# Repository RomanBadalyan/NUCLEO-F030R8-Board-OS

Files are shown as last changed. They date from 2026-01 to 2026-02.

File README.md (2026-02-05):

 

# Описание

Данный проект представляет собой __полное воссоздание оригинальной отладочной платы STM32 Nucleo-F030R8__ на базе микроконтроллера __STM32F030R8T6.__ Плата разработана с соблюдением всех габаритных размеров и расположения разъемов оригинального устройства, обеспечивая полную совместимость с экосистемой Arduino и ST Morpho.
Если хотите посмотреть всю докуметацию к проекту или самостоятельно воссоздать плату, переходите сразу в раздел ["Для разработчкиов"](https://github.com/RomanBadalyan/NUCLEO-F030R8-Board-OS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)

рисунок самой платы

## :dart: Ключевые особенности

* **100% совместимость** с оригинальной Nucleo-F030R8 по габаритам (70x82.5 мм) и распиновке
* **Двойная функциональность:** работает как отладочная плата и как программатор для других STM32
* **Полный набор интерфейсов:** Arduino Uno R3, ST Morpho, SWD, USB Virtual COM Port
* **Профессиональная 4-слойная структура** РСВ (улучшенная версия оригинальной 2-слойной)
* **Готовность к производству:** все файлы для заказа РСВ и компонентов включены

## :hammer_and_wrench: Технические характеристики

### Микроконтроллеры

* **Основной MCU:** STM32F030R8T6 (Cortex-M0, 64 КБ Flash, 8 КБ RAM, 48 МГц)
* **Программатор/отладчик:** STM32F103CBT6 (Cortex-M3, встроенный ST-LINK/V2-1)

### Питание

* **Вход USB:** 5V (500 мА максимум)
* **Вход VIN**: 7-12V (до 800 мА)
* **Выходы: 3.3V** (500 мА), 5V (до 800 мА)
* **Управление питанием:** Интеллектуальное включение MCU части

### Разъемы

* **Arduino Uno R3:** XP5, XP6, XP8, XP9 (полная совместимость с шилдами)
* **ST Morpho:** XP7, XP10 (полный доступ ко всем GPIO)
* **Отладка:** XP4 (SWD для внешних плат)
* **USB:** Mini-B для программирования и питания

### Особенности

* **Кварцы:** 8 МГц (в ST-LINK), 32.768 кГц (для RTC)
* **Индикация:** 3 светодиода (PWR, COM, USER)
* **Кнопки:** USER и RESET
* **Измерение потребления:** Перемычка XP6 для амперметра
______________
# 🔨 Для разработчиков
## Обзор проекта 
В данном репозитории представлен полный комплект проектно-конструкторской документации, а также все исходные файлы проекта для самостоятельного изготовления **отладочной платы Nucleo-F030R8.** Проект включает в себя все необходимые файлы для воссоздания оригинальной платы с возможностью последующей модификации под индивидуальные требования. Документация охватывает весь цикл проектирования — от принципиальных электрических схем до производственных файлов и спецификаций на покупные компоненты. Помимо этого всего, здесь представлены файлы с исходными библиотеками **Altium Designer,** которые Вы можете скачать и самостоятельно редактировать посадочные места, УГО или параметры компонентов. В последнем подразделе представлен BOM-файл с перечислением всех покупных компонентов и соответствующие им ссылки на **ЧИП и ДИП.**

***Важное примечание:** Представленная техническая документация разработана в учебных целях и не в полной мере соответствует требованиям Единой системы конструкторской документации (ЕСКД).*

## Исходные файлы с сайта st.com
В данном разделе перечислены все источники по разработке плат STM32 Nucleo 64 с официального сайта [STMicroelectronics](https://www.st.com/), в том числе и CAD-файлы и BOM-файлы для самостоятельной работы с проектом в **Altium Designer**
* [Описание проекта](https://www.st.com/en/evaluation-tools/nucleo-f030r8.html#overview)
* [Документация на плату и руководство пользователя](https://www.st.com/en/evaluation-tools/nucleo-f030r8.html#documentation)
* [CAD–файлы](https://www.st.com/en/evaluation-tools/nucleo-f030r8.html#cad-resources)
## Файлы проекта от автора 
### 📁 Файлы Altium Designer
Проект разработан в среде Altium Designer. Плата выполнена в 4-слойном исполнении, где на верхнем (Top) слое расположены все компоненты и сигнальные слои, на втором (L2) слое – общий слой земли, на третьем  (L3) слое два полигона питания для микроконтроллеров MCU (+3V3) и ST-LINK (+3V3_ST_LINK), а также оставшиеся цепи питания, на нижнем (Bottom) слое также общий слой земли и сигнальные цепи. Для редактирования всего проекта целиком откройте файл `МИЭМ.467999.001.PrjPcb`
* `МИЭМ.467999.001.PrjPcb` - Головной файл проекта Altium Designer
* `МИЭМ.467999.001Э3(1-4).SchDoc` - Принципиальная схема печатной платы
* `МИЭМ.467999.001.PcbDoc` - Файл топологии печатной платы
* `МИЭМ.467999.001СБ.PCBDwf` – Сборочные чертежи печатной платы
### 📁 Библиотеки 
В папке [Libraries](https://github.com/RomanBadalyan/NUCLEO-F030R8-Board-OS/tree/main/Libraries) представлены интегрированные библиотеки компонентов, использованные в проекте. Все библиотеки созданы в соответствии с ГОСТ и имеют единую структуру наименований. Для редактирования загрузите файлы с расширением **.LibPkg** в Altium Designer. Сборочные файлы имеют шаблон наименования компонентов **«Класс_компонента»_GOST.LibPkg**
### 📁 Gerber-файлы 
**Gerber-файлы** для заказа доступны в архиве [`МИЭМ.687253.001Т5М.zip`](https://github.com/RomanBadalyan/NUCLEO-F030R8-Board-OS/blob/main/Project%20Outputs%20for%20%D0%9C%D0%98%D0%AD%D0%9C.467999.001/%D0%9C%D0%98%D0%AD%D0%9C.687253.001%D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), который лежит в папке [Project Outputs for МИЭМ.467999.001](https://github.com/RomanBadalyan/NUCLEO-F030R8-Board-OS/tree/main/Project%20Outputs%20for%20%D0%9C%D0%98%D0%AD%D0%9C.467999.001) проект создавался с использованием [стека четырехслойной печатной платы](https://www.rezonit.ru/directory/v-pomoshch-konstruktoru/proektirovanie-elementov-konstrukcii-pechatnoj-platy-proizvodstva-v-rezonit/tipovye-sborki-i-konstruktsii-pe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) производителя [Резонит](https://www.rezonit.ru/), и правила проектирования также соответствуют [требованиям технологических возможностей](https://www.rezonit.ru/directory/tekhnologicheskie-osobennosti-proizvodstva/?active_tab=capabilities&type[]=urgent) данного производства
### 📁 Документация и BOM 
Документация в формате **.PDF** (не весь перечень) представлена в папке [Documents](https://github.com/RomanBadalyan/NUCLEO-F030R8-Board-OS/tree/main/Documents), а исходные файлы текстовой документации представлены в папке [Project Outputs for МИЭМ.467999.001](https://github.com/RomanBadalyan/NUCLEO-F030R8-Board-OS/tree/main/Project%20Outputs%20for%20%D0%9C%D0%98%D0%AD%D0%9C.467999.001) в формате **.XLS,** исходники чертежей (сборочные чертежи) имеют расширение **.Dwf** и лежат в основной ветке репозитория, их также можно открыть в Altium Designer и внести собственные изменения. В той же папке загружен [BOM-файл](https://github.com/RomanBadalyan/NUCLEO-F030R8-Board-OS/blob/main/Documents/%D0%9C%D0%98%D0%AD%D0%9C.467999.001BOM.xlsx), где, помимо наименований, перечислены также ссылки для заказа самих компонентов с интернет-магазина [ЧИП и ДИП](https://www.chipdip.ru/)
* [`МИЭМ.467999.001`](https://github.com/RomanBadalyan/NUCLEO-F030R8-Board-OS/blob/main/Documents/%D0%9C%D0%98%D0%AD%D0%9C.467999.001.pdf) - спецификация на печатный узел
* [`МИЭМ.467999.001СБ`](https://github.com/RomanBadalyan/NUCLEO-F030R8-Board-OS/blob/main/Documents/%D0%9C%D0%98%D0%AD%D0%9C.467999.001%D0%A1%D0%91.pdf) - сборочный чертеж на печатный узел
* [`МИЭМ.467999.001Э3`](https://github.com/RomanBadalyan/NUCLEO-F030R8-Board-OS/blob/main/Documents/%D0%9C%D0%98%D0%AD%D0%9C.467999.001%D0%AD3.pdf) - принципиальная схема
* [`МИЭМ.467999.001ВП`](https://github.com/RomanBadalyan/NUCLEO-F030R8-Board-OS/blob/main/Documents/%D0%9C%D0%98%D0%AD%D0%9C.467999.001%D0%92%D0%9F.pdf) - ведомость покупных изделий
* [`МИЭМ.467999.001ПЭ3`](https://github.com/RomanBadalyan/NUCLEO-F030R8-Board-OS/blob/main/Documents/%D0%9C%D0%98%D0%AD%D0%9C.467999.001%D0%9F%D0%AD3.pdf) - перечень элементов
* [`МИЭМ.687253.001`](https://github.com/RomanBadalyan/NUCLEO-F030R8-Board-OS/blob/main/Documents/%D0%9C%D0%98%D0%AD%D0%9C.687253.001.pdf) - спецификация на печатную плату
* [`МИЭМ.687253.001СБ`](https://github.com/RomanBadalyan/NUCLEO-F030R8-Board-OS/blob/main/Documents/%D0%9C%D0%98%D0%AD%D0%9C.687253.001%D0%A1%D0%91.pdf) - сборочный чертеж на печатную плату
* [`МИЭМ.687253.001Д1`](https://github.com/RomanBadalyan/NUCLEO-F030R8-Board-OS/blob/main/Documents/%D0%9C%D0%98%D0%AD%D0%9C.687253.001%D0%941.pdf) - данные конструкции

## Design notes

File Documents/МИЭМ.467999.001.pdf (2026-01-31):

Формат
Кол.
А3 | | МИЭМ.467999.001Э3 | Схема электрическая
| 2 Поз. | | принципиальная
А4 | | МИЭМ.467999.001ПЭ3 | Перечень элементов
| А3 | | | МИЭМ.467999.001ВП | Ведомость покупных изделий
| А3 | | | МИЭМ.467999.001СБ | Сборочный чертеж
А3 | 1
Изм. Лист | | № докум. | Подп. | Дата
| | Разраб. | Бадалян | | | Плата отладочная | Лит. | Лист | Листов
Пров. | | | | | У | | | 1 | 7
Вед. Инж. | Бадалян
Н. контр.
Утв.

Плата печатная

Сборочные единицы

Конденсаторы
100nF 10% 100В 125°C 0603 | 16 | C1, C4-C7,
CC0603KRX7R0BB104 Yageo | | C11, C12, C14,
| | C15, C19, C20,
| | C23, C24, C27,
| | C28, C30
3 | | 10nF 10% 100В 125°C 0603 | 1 | C9
| | CC0603KRX7R0BB103 Yageo
4 | | 10uF 10% 25В 125℃ 1411 | 2 | C16, C17
| | TAJB106K025RNJ Kyocera AVX

Документация

Подп. и дата Инв. № подл.

## МИЭМ.467999.001

Прочие изделия

1 МИЭМ.687253.001

Справ. №

Обозначение | Наименование

Подп. и дата

Примечание

Перв. примен.

Зона

Взам. инв. № Инв. № дубл.

Копировал | Формат А4

Изм. | Подп. | Дата

Взам. инв. № Инв. № дубл.

## МИЭМ.467999.001

Инв. № подл.
Лист

Подп. и дата Подп. и дата

| Микросхемы
9 | Микроконтроллер 32-Бит | 1 | DD2
| 72МГц 85°C LQFP-48
| STM32F103CBT6
| | | STMicroelectronics
| 10 | | Микроконтроллер ARM 48МГц | 1 | DD5
| | | 85°C LQFP64-10x10
| | | STM32F030R8T6
| | | STMicroelectronics
| 11 | | Стабилизатор напряжения | 1 | DA4
| | | линейный 5.5 В 125 °C DFN6
| | | (3x3 mm)
| | | STMicroelectronics
| 12 | | Стабилизатор напряжения | 1 | DA1
| | | линейный 6 В 125 °C
| | | SOT-23-5
| | | STMicroelectronics
| Конденсаторы
5 | 1uF 10% 10В 85°C 0603 | 5 | C2, C13, C18,
| GRM185R61A105K Murata | | C21, C29
| Electronics
| 20pF 5% 50В 125°C 0603 | 2 | C3, C8
| GRM1885C1H200J Murata
| Electronics
7 | 20pF 5% 50В 155°C 0603 | 2 | C33, C34
| GRM1885C1H200J Murata
| Electronics
8 | 4.3pF 1% 50В 125°C 0603 | 2 | C31, C32
| CC0603CRNPO9BN4R3 Yageo

№ докум.

6 Поз.

Взам. инв. № Инв. № дубл.

Инв. № подл.

Подп. и дата Подп. и дата

| Генераторы
15 | Осциллятор кварцевый | 1 | G2
| 0.002% 85°C QSMD8x3.8
| ABS25-32.768KHZ-6-T
| Осциллятор кварцевый 70°С | 1 | G3
| HC49SMD
17 | Осциллятор кварцевый 70°С | 1 | G1
| HC 49SMD
| Резисторы
18 | 0 1% 75В 0.1Вт 155°C 0603 | 7 | R17-R19,
| RC0603FR-070RL Yageo | | R34-R37
19 | 1.5kOhm 1% 50В 0.1Вт 155°C | 1 | R16
| 0603 RC0603FR-071K5L
20 | 100kOhm 1% 75В 0.1Вт 155°C | 3 | R6, R14, R15
| 0603 0603WAF1003T5E
| UNI-ROYAL(Uniroyal Elec)
21 | 100Ohm 1% 75В 0.1Вт 155°C | 6 | R11, R20, R21,
| 0603 AC0603FR-07100RL | | R24, R25, R29
| Yageo
22 | 10kOhm 1% 50В 0.1Вт 155°C | 4 | R1, R3, R12,
| 0603 RC0603FR-0710KL | | R33
| Элементы защиты по току
14 | Сердечник ферритовый 500мА | 1 | FA1
| 0603 FCM1608KF-601T05
| Микросхемы
13 | табилизатор напряжения 15 | 1 | DA3
16 Поз. | В 150 °C SOT-223
| STMicroelectronics

Взам. инв. № Инв. № дубл.

Инв. № подл.

Подп. и дата Подп. и дата

| Переключатели
29 | Выключатель кнопочный | 2 | SA1, SA2
| | | нажимной KAN0641-0431B
| Выключатели кнопочные
30 | Перемычка | 12 | SB3-SB10,
| | | SB12, SB15,
| | | SB45, SB60
25 Поз. | Резисторы
23 | 1kOhm 0.5% 50В 0.1Вт 155°C | 1 | R32
| 0603 RP0603DRD071KL Yageo
24 | 2.7kOhm 5% 75В 0.1Вт 155°C | 1 | R7
| 0603 RC0603JR-072K7L Yageo
| 22Ohm 1% 50В 0.1Вт 155°C | 4 | R5, R8, R13,
| 0603 RC0603FR-0722RL | | R22
26 | 36kOhm 5% 75В 0.1Вт 155°C | 1 | R10
| 0603 RC0603JR-0736KL Yageo
27 | 4.7kOhm 5% 75В 0.1Вт 155°C | 5 | R4, R23, R27,
| 0603 RC0603JR-074K7L Yageo | | R28, R30
28 | 510Ohm 1% 50В 0.063Вт | 1 | R31
| 155°C 0603
| RC0603FR-07510RL
Лист | № докум.

Взам. инв. № Инв. № дубл.

Инв. № подл.

Подп. и дата Подп. и дата

| Соединения контактные
36 | Разъем mini-USB на плату | 1 | X1
| SMD 1734035-1
37 | Соединение контактное | 1 | X6
| PLS_2
38 | Соединение контактное | 1 | X5
| PLS_3
| Транзисторы
34 | MOSFET 30В 2.5Вт 150°C | 1 | VT2
| SO-8 STS7PF30L
| STMicroelectronics
| | | NPN 40В 0.3Вт 150°C | 1 | VT1
| | | SOT-23-3 S9013 Hottech
| Диоды
32 | Диод Шоттки 10В 125°C | 3 | VD1-VD3
| SOD-323 STMicroelectronics
33 | Диод Шоттки 30В 150°C SMA | 1 | VD4
| STMicroelectronics
| Приборы электровакуумные и
| полупроводниковые
31 | Диод светоизлучающий | 4 | V2, V3, V11,
| Зеленый 0603 FYLS-0603PGC | | V12
35 Поз. | Ningbo Foryard
| Optoelectronics

Взам. инв. № Инв. № дубл.

Инв. № подл.

Подп. и дата Подп. и дата

41 Поз. | Вилки
39 | Соединение контактное | 1 | XP5
| PLS_10
40 | Соединение контактное | 2 | XP7, XP10
| PLS_19x2
| Соединение контактное | 4 | XP1, XP3,
| PLS_2 | | XP11, XP12
42 | Соединение контактное | 1 | XP2
| PLS_4
43 | Соединение контактное | 2 | XP4, XP8
| PLS_6
44 | Соединение контактное | 2 | XP6, XP9
| PLS_8
Лист | № докум.

Изм. | Дата

Подп.

Лист регистрации изменений

Изм. | Номера листов (страниц) | Всего листов (страниц) в докум. | № докум. | Входящий № сопроводи-тельного документа и дата | Под-пись | Дата
изме-ненных | заме-няемых | новых | аннули-рованных

№ докум

Инв. № дубл. Инв.№ подл. Подп. и дата Взам. инв. №

Подп. и дата

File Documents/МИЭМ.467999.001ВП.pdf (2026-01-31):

| Конденсаторы
1 | 100nF 10% 100В 125°C 0603 | | | Yageo | 16
| CC0603KRX7R0BB104 Yageo
| | 2 | 10nF 10% 100В 125°C 0603 | | Yageo | 1
| | | CC0603KRX7R0BB103 Yageo
| | 3 | 10uF 10% 25В 125℃ 1411 | | Kyocera AVX | 2
| | | TAJB106K025RNJ Kyocera AVX
| | 4 | 1uF 10% 10В 85°C 0603 | | Murata Electronics | 5
| | | GRM185R61A105K Murata
| | | Electronics
| | 5 | 20pF 5% 50В 125°C 0603 | | Murata Electronics | 2
| | | GRM1885C1H200J Murata
| | | Electronics
| | 6 | 20pF 5% 50В 155°C 0603 | | Murata Electronics | 2
| | | GRM1885C1H200J Murata
| | | Electronics
| | 7 | 4.3pF 1% 50В 125°C 0603 | | Yageo | 2
| | | CC0603CRNPO9BN4R3 Yageo
| Микросхемы
8 | Микроконтроллер 32-Бит 72МГц | STMicroelectronics | 1
| 85°C LQFP-48 STM32F103CBT6
| STMicroelectronics
Изм. | Лист | № докум. | Подп. | Дата
Разраб. | Бадалян | | | Плата отладочная Ведомость покупных изделий | Лит. | Лист | Листов
Пров. | | | | | У | | | 1 | 6
Вед. Инж. | Бадалян
Н. контр.
Утв.

Справ. № Подп. и дата

Перв. примен.

МИЭМ.467999.001

Взам. инв. № Инв. № дубл.

| | | Наименование | Код продукции | Обозначение документа на поставки | Поставщик | Куда входит (обозначение) | Количество | Примечание
На изделие | В компл-екты | регу-лир. | Всего
| Прочие изделия

Подп. и дата

№ строки

Инв. № подл.

## МИЭМ.467999.001 ВП

Копировал | Формат А3

изделие | В комп-екты | На ре-гулир.
| Микросхемы
9 | Микроконтроллер ARM 48МГц | | STMicroelectronics | 1
| 85°C LQFP64-10x10
| STM32F030R8T6
| STMicroelectronics
10 | Стабилизатор напряжения | | STMicroelectronics | 1
| линейный 5.5 В 125 °C DFN6
| (3x3 mm) STMicroelectronics
11 | Стабилизатор напряжения | | STMicroelectronics | 1
| линейный 6 В 125 °C SOT-23-5
| STMicroelectronics
12 | табилизатор напряжения 15 В | | STMicroelectronics | 1
| 150 °C SOT-223
| STMicroelectronics

Элементы защиты по току
| 13 | Сердечник ферритовый 500мА | 1
| | 0603 FCM1608KF-601T05
| Генераторы
14 | Осциллятор кварцевый 0.002% | | | 1
| 85°C QSMD8x3.8
| ABS25-32.768KHZ-6-T
| | 15 | Осциллятор кварцевый 70°С | | 1
| | | HC49SMD
| | 16 | Осциллятор кварцевый 70°С | | 1
| | | HC 49SMD
| Резисторы
17 | 0 1% 75В 0.1Вт 155°C 0603 | | Yageo | 7
| | RC0603FR-070RL Yageo
| | | | МИЭМ.467999.001 ВП | Лист

Инв. № подл.

Изм. Лист | Подп. | Дата

Подп. и дата

№ докум. | 2

Взам. инв. № Инв. № дубл. Подп. и дата

№ строки
Наименование | Код продукции | Обозначение документа на поставку | Поставщик

изделие | екты | гулир.
| Резисторы
18 | 1.5kOhm 1% 50В 0.1Вт 155°C | | | | 1
| 0603 RC0603FR-071K5L
19 | 100kOhm 1% 75В 0.1Вт 155°C | | | UNI-ROYAL(Uniroyal Elec) | 3
| 0603 0603WAF1003T5E
| UNI-ROYAL(Uniroyal Elec)
20 100Ohm 1% 75В 0.1Вт 155°C | | | | Yageo | 6
| 0603 AC0603FR-07100RL Yageo
21 | 10kOhm 1% 50В 0.1Вт 155°C | | | | 4
| 0603 RC0603FR-0710KL
22 1kOhm 0.5% 50В 0.1Вт 155°C | | | | Yageo | 1
| 0603 RP0603DRD071KL Yageo
23 2.7kOhm 5% 75В 0.1Вт 155°C | | | | Yageo | 1
| 0603 RC0603JR-072K7L Yageo
24 22Ohm 1% 50В 0.1Вт 155°C | | | | | 4
| 0603 RC0603FR-0722RL
| | 25 36kOhm 5% 75В 0.1Вт 155°C | | | Yageo | 1
| | | 0603 RC0603JR-0736KL Yageo
| | 26 4.7kOhm 5% 75В 0.1Вт 155°C | | | Yageo | 5
| | | 0603 RC0603JR-074K7L Yageo
| | 27 510Ohm 1% 50В 0.063Вт 155°C | | | | 1
| | | 0603 RC0603FR-07510RL
| Переключатели
28 Выключатель кнопочный | | 2
| нажимной KAN0641-0431B

Приборы электровакуумные
и полупроводниковые

Инв. № подл.

Подп. и дата

Взам. инв. № Инв. № дубл. Подп. и дата

№ строки

изделие | екты | гулир.
| Приборы электровакуумные
| и полупроводниковые
29 Диод светоизлучающий Зеленый | | | Ningbo Foryard | 4
| 0603 FYLS-0603PGC Ningbo | | Optoelectronics
| Foryard Optoelectronics
| Диоды
30 Диод Шоттки 10В 125°C | | STMicroelectronics | 3
| SOD-323 STMicroelectronics
31 | Диод Шоттки 30В 150°C SMA | STMicroelectronics | 1
| STMicroelectronics
| Транзисторы
32 MOSFET 30В 2.5Вт 150°C SO-8 | | | STMicroelectronics | 1
| STS7PF30L STMicroelectronics
33 NPN 40В 0.3Вт 150°C SOT-23-3 | | | Hottech | 1
| | S9013 Hottech
| Соединения контактные
34 Разъем mini-USB на плату SMD | | 1
| 1734035-1
35 Соединение контактное PLS_2 | | 1
36 Соединение контактное PLS_3 | | 1
| Вилки
37 Соединение контактное PLS_10 | | | | 1
38 Соединение контактное | | | | 2
| PLS_19x2
39 Соединение контактное PLS_2 | | | | 4
40 Соединение контактное PLS_4 | | | | 1
| | 41 | Соединение контактное PLS_6 | | 2

Инв. № подл.

Подп. и дата

Взам. инв. № Инв. № дубл. Подп. и дата

№ строки

изделие | екты | гулир.
| Вилки
42 Соединение контактное PLS_8 | | | 2

Инв. № подл.

Подп. и дата

Взам. инв. № Инв. № дубл. Подп. и дата

№ строки
Наименование | Код продукции | Обозначение документа на поставку | Поставщик | Куда входит (обозначение)

Изм. | Дата
Изм. | Номера листов (страниц) | Всего листов (страниц) в докум. | № докум. | Входящий № сопроводи-тельного документа и дата | Под-пись | Дата
изме-ненных | заме-няемых | новых | аннули-рованных

Подп. и дата

Лист регистрации изменений

Инв. № дубл. Инв.№ подл. Подп. и дата Взам. инв. №

6
Подп.

№ докум

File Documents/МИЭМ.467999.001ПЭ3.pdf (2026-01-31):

Изм.Лист | | № докум. | Подп. | Дата
| | Разраб. | Бадалян | | | Плата отладочная Перечень элементов Копировал | Лит. | Лист | Листов
Пров. | | | | | У | | | 1 | 6
Вед. Инж. | Бадалян | | | | МИЭМ Формат А4
Н.контр
Утв.
C1 | 100nF 10% 100В 125°C 0603 CC0603KRX7R0BB104 Yageo | 1
C2 | 1uF 10% 10В 85°C 0603 GRM185R61A105K Murata Electronics | 1
C3 | 20pF 5% 50В 125°C 0603 GRM1885C1H200J Murata | 1
| Electronics
C4-C7 | 100nF 10% 100В 125°C 0603 CC0603KRX7R0BB104 Yageo | 4
C8 | 20pF 5% 50В 125°C 0603 GRM1885C1H200J Murata | 1
| Electronics
C9 | 10nF 10% 100В 125°C 0603 CC0603KRX7R0BB103 Yageo | 1
C11,C12 | 100nF 10% 100В 125°C 0603 CC0603KRX7R0BB104 Yageo | 2
C13 | 1uF 10% 10В 85°C 0603 GRM185R61A105K Murata Electronics | 1
C14,C15 | 100nF 10% 100В 125°C 0603 CC0603KRX7R0BB104 Yageo | 2
C16,C17 | 10uF 10% 25В 125℃ 1411 TAJB106K025RNJ Kyocera AVX | 2
C18 | 1uF 10% 10В 85°C 0603 GRM185R61A105K Murata Electronics | 1
C19,C20 | 100nF 10% 100В 125°C 0603 CC0603KRX7R0BB104 Yageo | 2
C21 | 1uF 10% 10В 85°C 0603 GRM185R61A105K Murata Electronics | 1
C23,C24 | 100nF 10% 100В 125°C 0603 CC0603KRX7R0BB104 Yageo | 2
| | C27,C28 | 100nF 10% 100В 125°C 0603 CC0603KRX7R0BB104 Yageo | 2
| | C29 | 1uF 10% 10В 85°C 0603 GRM185R61A105K Murata Electronics | 1
| | C30 | 100nF 10% 100В 125°C 0603 CC0603KRX7R0BB104 Yageo | 1
| | C31,C32 | 4.3pF 1% 50В 125°C 0603 CC0603CRNPO9BN4R3 Yageo | 2
| | C33,C34 | 20pF 5% 50В 155°C 0603 GRM1885C1H200J Murata | 2
| | | Electronics

Перв. примен.

МИЭМ.467999.001

Поз.
обозначение

Наименование
Кол. Примечание

Конденсаторы

Справ. №

Инв. № подл.

Подп. и дата

Подп. и дата Взам. инв.№ Инв. № дубл.

## МИЭМ.467999.001ПЭ3

Изм. Лист | Подп. | Дата

Микросхемы

DA1 | Стабилизатор напряжения линейный 6 В 125 °C SOT-23-5 | 1
| STMicroelectronics
DA3 | табилизатор напряжения 15 В 150 °C SOT-223 | 1
| STMicroelectronics
DA4 | Стабилизатор напряжения линейный 5.5 В 125 °C DFN6 (3x3 | 1
| mm) STMicroelectronics
DD2 | Микроконтроллер 32-Бит 72МГц 85°C LQFP-48 STM32F103CBT6 | 1
| STMicroelectronics
DD5 | Микроконтроллер ARM 48МГц 85°C LQFP64-10x10 | 1
| STM32F030R8T6 STMicroelectronics

Элементы защиты по току

Подп. и дата
FA1 | Сердечник ферритовый 500мА 0603 FCM1608KF-601T05 | 1
| Генераторы
Инв. № дубл.
G1 | Осциллятор кварцевый 70°С HC 49SMD | 1
G2 | Осциллятор кварцевый 0.002% 85°C QSMD8x3.8 | 1
| | | ABS25-32.768KHZ-6-T
| | G3 | Осциллятор кварцевый 70°С HC49SMD | 1
R1,R3 | 10kOhm 1% 50В 0.1Вт 155°C 0603 RC0603FR-0710KL | 2
R4 | 4.7kOhm 5% 75В 0.1Вт 155°C 0603 RC0603JR-074K7L Yageo | 1
R5 | 22Ohm 1% 50В 0.1Вт 155°C 0603 RC0603FR-0722RL | 1
R6 | 100kOhm 1% 75В 0.1Вт 155°C 0603 0603WAF1003T5E | 1
| UNI-ROYAL(Uniroyal Elec)
| | | МИЭМ.467999.001ПЭ3 | Лист

Резисторы

№ докум.

Подп. и дата Взам. инв.№

Инв. № подл.

Резисторы

R7 | 2.7kOhm 5% 75В 0.1Вт 155°C 0603 RC0603JR-072K7L Yageo | 1
R8 | 22Ohm 1% 50В 0.1Вт 155°C 0603 RC0603FR-0722RL | 1
R10 | 36kOhm 5% 75В 0.1Вт 155°C 0603 RC0603JR-0736KL Yageo | 1
R11 | 100Ohm 1% 75В 0.1Вт 155°C 0603 AC0603FR-07100RL Yageo | 1
R12 | 10kOhm 1% 50В 0.1Вт 155°C 0603 RC0603FR-0710KL | 1
R13 | 22Ohm 1% 50В 0.1Вт 155°C 0603 RC0603FR-0722RL | 1
R14,R15 | 100kOhm 1% 75В 0.1Вт 155°C 0603 0603WAF1003T5E | 2
| UNI-ROYAL(Uniroyal Elec)
R16 | 1.5kOhm 1% 50В 0.1Вт 155°C 0603 RC0603FR-071K5L | 1
R17-R19 | 0 1% 75В 0.1Вт 155°C 0603 RC0603FR-070RL Yageo | 3
R20,R21 | 100Ohm 1% 75В 0.1Вт 155°C 0603 AC0603FR-07100RL Yageo | 2
R22 | 22Ohm 1% 50В 0.1Вт 155°C 0603 RC0603FR-0722RL | 1
| | R23 | 4.7kOhm 5% 75В 0.1Вт 155°C 0603 RC0603JR-074K7L Yageo | 1
| | R24,R25 | 100Ohm 1% 75В 0.1Вт 155°C 0603 AC0603FR-07100RL Yageo | 2
| | R27,R28 | 4.7kOhm 5% 75В 0.1Вт 155°C 0603 RC0603JR-074K7L Yageo | 2
| | R29 | 100Ohm 1% 75В 0.1Вт 155°C 0603 AC0603FR-07100RL Yageo | 1
| | R30 | 4.7kOhm 5% 75В 0.1Вт 155°C 0603 RC0603JR-074K7L Yageo | 1
| | R31 | 510Ohm 1% 50В 0.063Вт 155°C 0603 RC0603FR-07510RL | 1
| | R32 | 1kOhm 0.5% 50В 0.1Вт 155°C 0603 RP0603DRD071KL Yageo | 1
| | R33 | 10kOhm 1% 50В 0.1Вт 155°C 0603 RC0603FR-0710KL | 1
| | R34-R37 | 0 1% 75В 0.1Вт 155°C 0603 RC0603FR-070RL Yageo | 4

Подп. и дата

Инв. № дубл.

SA1,SA2

Переключатели

Подп. и дата Взам. инв.№

Выключатель кнопочный нажимной KAN0641-0431B | 2

Инв. № подл.

Выключатели кнопочные

SB3-SB10 Перемычка | 8
SB12,SB15 Перемычка | 2
SB45,SB60 Перемычка | 2
V2,V3 | Диод светоизлучающий Зеленый 0603 FYLS-0603PGC Ningbo | 2
| Foryard Optoelectronics
V11,V12 | Диод светоизлучающий Зеленый 0603 FYLS-0603PGC Ningbo | 2
| Foryard Optoelectronics

Приборы электровакуумные и полупроводниковые

Диоды

Подп. и дата
VD1-VD3 | Диод Шоттки 10В 125°C SOD-323 STMicroelectronics | 3
VD4 | Диод Шоттки 30В 150°C SMA STMicroelectronics | 1

Инв. № дубл.
Транзисторы
VT1 | NPN 40В 0.3Вт 150°C SOT-23-3 S9013 Hottech | 1
| | VT2 | MOSFET 30В 2.5Вт 150°C SO-8 STS7PF30L | 1
| | | STMicroelectronics
X1 | Разъем mini-USB на плату SMD 1734035-1 | 1
X5 | Соединение контактное PLS_3 | 1
X6 | Соединение контактное PLS_2 | 1

Соединения контактные

Подп. и дата Взам. инв.№

Инв. № подл.

Вилки

XP1 | Соединение контактное PLS_2 | 1
XP2 | Соединение контактное PLS_4 | 1
XP3 | Соединение контактное PLS_2 | 1
XP4 | Соединение контактное PLS_6 | 1
XP5 | Соединение контактное PLS_10 | 1
XP6 | Соединение контактное PLS_8 | 1
XP7 | Соединение контактное PLS_19x2 | 1
XP8 | Соединение контактное PLS_6 | 1
XP9 | Соединение контактное PLS_8 | 1
XP10 | Соединение контактное PLS_19x2 | 1
XP11,XP12 Соединение контактное PLS_2 | | 2

Подп. и дата Инв. № дубл.

Подп. и дата Взам. инв.№ Инв. № подл.

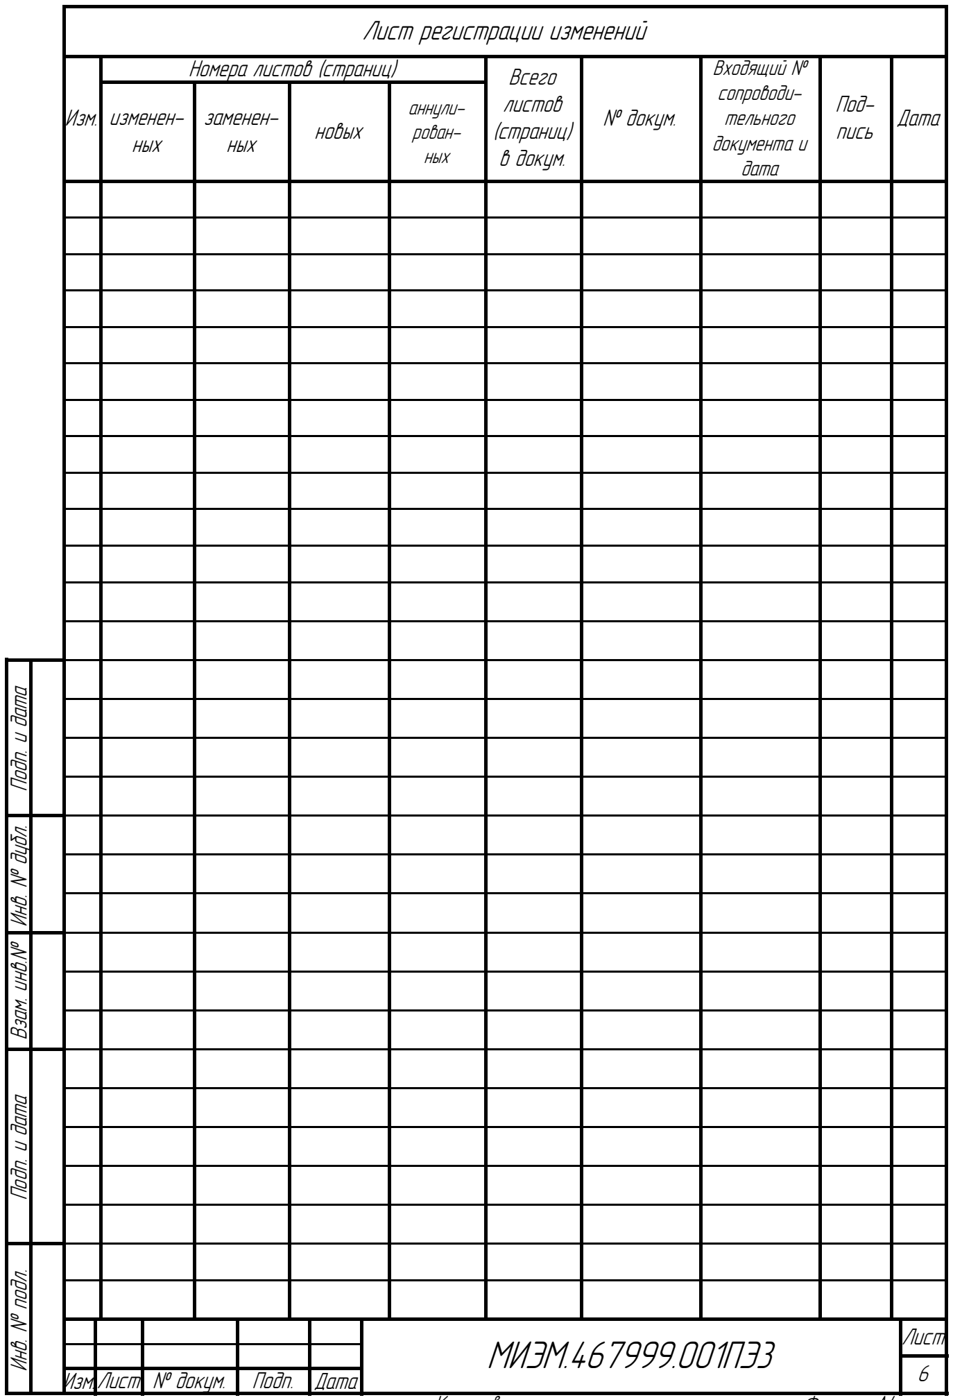
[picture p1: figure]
аннули- рован- ных; Изм.; Дата; заменен- ных; № докум.; Подп.; новых; Номера листов (страниц); Всего листов (страниц) в докум.; Входящий № сопроводи- тельного документа и дата; Под- пись; Лист регистрации изменений; Изм. изменен- ных

Инв. № дубл. Подп. и дата Инв. № подл. Подп. и дата Взам. инв.№

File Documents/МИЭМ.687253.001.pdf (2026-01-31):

Формат
Кол.
А3 | | МИЭМ.687253.001СБ | Сборочный чертеж
| | МИЭМ.687253.001Т5М | Данные конструкции
А4 | | МИЭМ.687253.001Д1 | Данные проектирования
| А3
| А3 | | | Материалы
Стеклоткань FR4 TG150 0,115 мм | 2 | Слои 1, 4
(Фольга 35 мкм)
Стеклотекстолит FR4 TG150 | 1 | Слои 2-3
(Фольга 35 мкм)
Изм. Лист | | № докум. | Подп. | Дата
| | Разраб. | Бадалян | | | Плата печатная многослойная Копировал | Лит. | Лист | Листов
Пров. | | | | | У | | | 1 | 2
Вед. Инж. | Бадалян | | | | Формат А4
Н. контр.
Утв.

Взам. инв. № Инв. № дубл. Подп. и дата

Примечание

Перв. примен.

МИЭМ.467999.001

Зона
Поз.
Обозначение | Наименование

Справ. №

## МИЭМ.687253.001

Документация

Подп. и дата Инв. № подл.

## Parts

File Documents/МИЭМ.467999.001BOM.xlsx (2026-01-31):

Designator | Name | Footprint | PartNumber | Quantity | Source
C1, C4, C5, C6, C7, C11, C12, C14, C15, C19, C20, C23, C24, C27, C28, C30 | 100nF | 0603 | CC0603KRX7R0BB104 | 16 | https://www.chipdip.ru/product/0.1mkf-x7r-100v-10-0603-cc0603krx7r0bb104-kondensator-yageo-9000578715, [NoValue]
C2, C13, C18, C21, C29 | 1uF | 0603 | GRM185R61A105K | 5 | https://www.chipdip.ru/product/1mkf-x5r-10v-10-0603-grm185r61a105k-kondensator-murata-767906735
C3, C8, C33, C34 | 20pF | 0603 | GRM1885C1H200J | 4 | https://www.chipdip.ru/product/20pf-np0-50v-5-0603-grm1885c1h200j-kondensator-murata-268501846
C9 | 10nF | 0603 | CC0603KRX7R0BB103 | 1 | https://www.chipdip.ru/product/0.01mkf-x7r-100v-10-0603-cc0603krx7r0bb103-yageo-9000501772
C16, C17 | 10uF | TAJB106K025R | TAJB106K025RNJ | 2 | [NoValue], https://www.chipdip.ru/product/tajb106k025rnj-kyocera-avx-8002005515
C31, C32 | 4.3pF | 0603 | CC0603CRNPO9BN4R3 | 2 | https://www.chipdip.ru/product/4.3pf-np0-50v-0.25pf-0603-cc0603crnpo9bn4r3-yageo-9000952764
DA1 | LD3985M33R | LD3985M33R (SOT-23-5) |  | 1 | https://www.chipdip.ru/product/ld3985m33r-regulyator-s-nizkim-padeniem-st-microelectronics-9060001543
DA3 | LD1117S50TR | LD1117S50TR (SOT-223) |  | 1 | https://static.chipdip.ru/lib/432/DOC004432359.pdf
DA4 | LD39050PU33R | LD39050PU33R (DFN6 (3x3 mm)) |  | 1 | https://www.chipdip.ru/product/ld39050pu33r-regulyator-napryazheniya-st-microelectronics-9000811056
DD2 | STM32F103CBT6 | LQFP48-7x7mm | STM32F103CBT6 | 1 | https://www.chipdip.ru/product/stm32f103cbt6-mikrokontroller-32-bit-st-microelectronics-9000052539
DD5 | STM32F030R8T6 | LQFP64-10x10mm | STM32F030R8T6 | 1 | https://www.chipdip.ru/product/stm32f030r8t6-mikrokontroller-arm-st-microelectronics-9000247632
FA1 | 500мА | FCM1608KF-601T05 | FCM1608KF-601T05 | 1 | https://www.chipdip.ru/product/fcm1608kf-601t05-tai-tech-8040727428
G1, G3 | Oscillator | HC49SMD |  | 2 | https://www.chipdip.ru/product/hc49smd-8-mhz-20pf-30ppm-kvartsevyy-rezonator-ruichi-8007334696, https://www.chipdip.ru/product/hc49smd-8-mhz-20pf-30ppm-ruichi-8022445237
G2 | Oscillator | ABS25-32.768KHZ-6-T | ABS25-32.768KHZ-6-T | 1 | https://www.chipdip.ru/product/abs25-32.768khz-6-t-abracon-8001972524
R1, R3, R12, R33 | 10kOhm | 0603 | RC0603FR-0710KL | 4 | https://www.chipdip.ru/product/0.1vt-0603-10-kom-1-chip-rezistor-smd-9000079736
R4, R23, R27, R28, R30 | 4.7kOhm | 0603 | RC0603JR-074K7L | 5 | https://www.chipdip.ru/product/0.1vt-0603-4.7-kom-5-rc0603jr-074k7l-chip-rezistor-yageo-9000301240
R5, R8, R13, R22 | 22Ohm | 0603 | RC0603FR-0722RL | 4 | https://www.chipdip.ru/product/0.1vt-0603-22-om-1-chip-rezistor-smd-9000079564
R6, R14, R15 | 100kOhm | 0603 | 0603WAF1003T5E | 3 | https://www.chipdip.ru/product/0603waf1003t5e-rezistor-tolstoplenochnyy-100mvt-uni-royal-8033183962
R7 | 2.7kOhm | 0603 | RC0603JR-072K7L | 1 | https://www.chipdip.ru/product/0.1vt-0603-2.7-kom-5-rc0603jr-072k7l-chip-rezistor-yageo-9000381530
R10 | 36kOhm | 0603 | RC0603JR-0736KL | 1 | https://www.chipdip.ru/product/0.1vt-0603-36-kom-5-rc0603jr-0736kl-chip-rezistor-smd-yageo-9001745834
R11, R20, R21, R24, R25, R29 | 100Ohm | 0603 | AC0603FR-07100RL | 6 | https://www.chipdip.ru/product/0.1vt-0603-100-om-1-ac0603fr-07100rl-chip-rezistor-yageo-9000495858
R16 | 1.5kOhm | 0603 | RC0603FR-071K5L | 1 | https://www.chipdip.ru/product/0.1vt-0603-1.5-kom-1-chip-rezistor-smd-9000079716
R17, R18, R19, R34, R35, R36, R37 | 0 | 0603 | RC0603FR-070RL | 7 | https://www.chipdip.ru/product/0.1vt-0603-0-om-1-rc0603fr-070rl-chip-rezistor-smd-yageo-9001227234
R31 | 510Ohm | 0603 | RC0603FR-07510RL | 1 | https://www.chipdip.ru/product/0.1vt-0603-510-om-1-chip-rezistor-smd-9000079669
R32 | 1kOhm | 0603 | RP0603DRD071KL | 1
SA1, SA2 | Button_4pin | Button_4pin | KAN0641-0431B | 2 | https://www.chipdip.ru/product/taktovaya-knopka-6.0x-4.3-algoritm-raboty-no-td-06xg-9000914059
SB3, SB4, SB5, SB6, SB7, SB8, SB9, SB10, SB12, SB15, SB45, SB60 | Jumper | Jumper |  | 12
V2, V3, V11, V12 | led | FYLS-0603PGC | FYLS-0603PGC | 4 | https://www.chipdip.ru/product/fyls-0603pgc-svetodiod-smd-1-6x0-8mm-zelenyy-525nm-foryard-9000204615, [NoValue]
VD1, VD2, VD3 | BAT60JFILM | BAT60JFILM |  | 3 | https://www.chipdip.ru/product/bat60jfilm-diod-shottki-3a-10v-sod-323-st-microelectronics-9000198985
VD4 | STPS2L30A | STPS2L30A |  | 1 | https://www.chipdip.ru/product/stps2l30a-st-microelectronics-8001998231
VT1 | S9013 (MMBT9013L/G) | S9013 (SOT_23_3) | S9013 | 1 | https://www.chipdip.ru/product/s9013-tranzistor-npn-25v-0.5a-hfe-120-400-0.3vt-hottech-9001276075
VT2 | STS7PF30L | STS7PF30L | STS7PF30L | 1 | https://www.chipdip.ru/product/sts7pf30l-vb-mop-tranzistor-30-v-9-a-18-m-10-p-kanal-vbsemi-8015911998
X1 | USB-MINI-B-SMD | USB-MINI-B-SMD | 1734035-1 | 1 | https://www.chipdip.ru/product/1734035-1-razem-mini-usb-na-platu-smd-te-connectivity-9000149111
X5 | PLS_3 | PLS_3 | PLS_3 | 1
X6, XP1, XP3, XP11, XP12 | PLS_2 | PLS_2 | PLS_2 | 5
XP2 | PLS_4 | PLS_4 | PLS_4 | 1
XP4, XP8 | PLS_6 | PLS_6 | PLS_6 | 2
XP5 | PLS_10 | PLS_10 | PLS_10 | 1
XP6, XP9 | PLS_8 | PLS_8 | PLS_8 | 2
XP7, XP10 | PLS_19x2 | PLS_19x2 | PLS_19x2 | 2

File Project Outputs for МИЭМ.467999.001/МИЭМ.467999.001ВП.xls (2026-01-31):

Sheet: МИЭМ.467999.001. Первый лист.
Перв. примен. | МИЭМ.467999.001 | № строки | Наименование | Код продукции | Обозначение документа на поставки | Поставщик |  |  |  | Куда входит (обозначение) |  |  |  | Количество |  |  |  |  |  | Примечание
 |  |  |  |  |  |  |  |  |  |  |  |  |  | На изделие | В компл-екты | На регу-лир. |  | Всего
 |  |  | Прочие изделия
 |  |  | Конденсаторы
 |  | 1 | 100nF 10% 100В 125°C 0603 |  |  | Yageo |  |  |  |  |  |  |  | 16
 |  |  | CC0603KRX7R0BB104 Yageo
Справ. № |  | 2 | 10nF 10% 100В 125°C 0603 |  |  | Yageo |  |  |  |  |  |  |  | 1
 |  |  | CC0603KRX7R0BB103 Yageo
 |  | 3 | 10uF 10% 25В 125℃ 1411 |  |  | Kyocera AVX |  |  |  |  |  |  |  | 2
 |  |  | TAJB106K025RNJ Kyocera AVX
 |  | 4 | 1uF 10% 10В 85°C 0603 |  |  | Murata Electronics |  |  |  |  |  |  |  | 5
 |  |  | GRM185R61A105K Murata
 |  |  | Electronics
 |  | 5 | 20pF 5% 50В 125°C 0603 |  |  | Murata Electronics |  |  |  |  |  |  |  | 2
 |  |  | GRM1885C1H200J Murata
 |  |  | Electronics
 |  | 6 | 20pF 5% 50В 155°C 0603 |  |  | Murata Electronics |  |  |  |  |  |  |  | 2
Подп. и дата |  |  | GRM1885C1H200J Murata
 |  |  | Electronics
 |  | 7 | 4.3pF 1% 50В 125°C 0603 |  |  | Yageo |  |  |  |  |  |  |  | 2
 |  |  | CC0603CRNPO9BN4R3 Yageo
Инв. № дубл.
 |  |  | Микросхемы
 |  | 8 | Микроконтроллер 32-Бит 72МГц |  |  | STMicroelectronics |  |  |  |  |  |  |  | 1
Взам. инв. № |  |  | 85°C LQFP-48 STM32F103CBT6
 |  |  | STMicroelectronics
Подп. и дата
 |  |  |  |  |  |  |  |  |  |  |  |  | МИЭМ.467999.001 ВП
 |  |  |  |  |  |  | Изм. | Лист | № докум. |  | Подп. | Дата
Инв. № подл. |  |  |  |  |  |  | Разраб. |  | Бадалян |  |  |  | Плата отладочная |  |  |  | Лит. |  | Лист |  | Листов
 |  |  |  |  |  |  | Пров. |  |  |  |  |  |  |  |  |  | У |  | 1 |  | 6
 |  |  |  |  |  |  | Вед. Инж. |  | Бадалян
 |  |  |  |  |  |  | Н. контр.
 |  |  |  |  |  |  | Утв. |  |  |  |  |  | Ведомость покупных изделий

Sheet: 2
 |  | № строки | Наименование | Код продукции | Обозначение документа на поставку | Поставщик |  |  |  | Куда входит (обозначение) |  |  |  | Количество |  |  |  | Примечание
-00 |  |  |  |  |  |  |  |  |  |  |  |  |  | На изделие | В комп-екты | На ре-гулир. | Всего
 |  |  | Микросхемы
 |  | 9 | Микроконтроллер ARM 48МГц |  |  | STMicroelectronics |  |  |  |  |  |  |  | 1
 |  |  | 85°C LQFP64-10x10
 |  |  | STM32F030R8T6
 |  |  | STMicroelectronics
 |  | 10 | Стабилизатор напряжения |  |  | STMicroelectronics |  |  |  |  |  |  |  | 1
 |  |  | линейный 5.5 В 125 °C DFN6
 |  |  | (3x3 mm) STMicroelectronics
 |  | 11 | Стабилизатор напряжения |  |  | STMicroelectronics |  |  |  |  |  |  |  | 1
 |  |  | линейный 6 В 125 °C SOT-23-5
 |  |  | STMicroelectronics
 |  | 12 | табилизатор напряжения 15 В |  |  | STMicroelectronics |  |  |  |  |  |  |  | 1
 |  |  | 150 °C SOT-223
 |  |  | STMicroelectronics
 |  |  | Элементы защиты по току
 | Подп. и дата | 13 | Сердечник ферритовый 500мА |  |  |  |  |  |  |  |  |  |  | 1
 |  |  | 0603 FCM1608KF-601T05
 |  |  | Генераторы
 | Инв. № дубл. | 14 | Осциллятор кварцевый 0.002% |  |  |  |  |  |  |  |  |  |  | 1
 |  |  | 85°C QSMD8x3.8
 |  |  | ABS25-32.768KHZ-6-T
 | Взам. инв. № | 15 | Осциллятор кварцевый 70°С |  |  |  |  |  |  |  |  |  |  | 1
 |  |  | HC49SMD
 |  | 16 | Осциллятор кварцевый 70°С |  |  |  |  |  |  |  |  |  |  | 1
 | Подп. и дата |  | HC 49SMD
 |  |  | Резисторы
 |  | 17 | 0 1% 75В 0.1Вт 155°C 0603 |  |  | Yageo |  |  |  |  |  |  |  | 7
 | Инв. № подл. |  | RC0603FR-070RL Yageo
 |  |  |  |  |  |  |  |  |  |  |  |  | МИЭМ.467999.001 ВП |  |  |  |  |  | Лист
 |  |  |  |  |  |  |  |  |  |  |  |  |  |  |  |  |  |  | 2
 |  |  |  |  |  |  | Изм. | Лист | № докум. |  | Подп. | Дата

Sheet: 3
 |  | № строки | Наименование | Код продукции | Обозначение документа на поставку | Поставщик |  |  |  | Куда входит (обозначение) |  |  |  | Количество |  |  |  | Примечание
-00 |  |  |  |  |  |  |  |  |  |  |  |  |  | На изделие | В комп-екты | На ре-гулир. | Всего
 |  |  | Резисторы
 |  | 18 | 1.5kOhm 1% 50В 0.1Вт 155°C |  |  |  |  |  |  |  |  |  |  | 1
 |  |  | 0603 RC0603FR-071K5L
 |  | 19 | 100kOhm 1% 75В 0.1Вт 155°C |  |  | UNI-ROYAL(Uniroyal Elec) |  |  |  |  |  |  |  | 3
 |  |  | 0603 0603WAF1003T5E
 |  |  | UNI-ROYAL(Uniroyal Elec)
 |  | 20 | 100Ohm 1% 75В 0.1Вт 155°C |  |  | Yageo |  |  |  |  |  |  |  | 6
 |  |  | 0603 AC0603FR-07100RL Yageo
 |  | 21 | 10kOhm 1% 50В 0.1Вт 155°C |  |  |  |  |  |  |  |  |  |  | 4
 |  |  | 0603 RC0603FR-0710KL
 |  | 22 | 1kOhm 0.5% 50В 0.1Вт 155°C |  |  | Yageo |  |  |  |  |  |  |  | 1
 |  |  | 0603 RP0603DRD071KL Yageo
 |  | 23 | 2.7kOhm 5% 75В 0.1Вт 155°C |  |  | Yageo |  |  |  |  |  |  |  | 1
 |  |  | 0603 RC0603JR-072K7L Yageo
 |  | 24 | 22Ohm 1% 50В 0.1Вт 155°C |  |  |  |  |  |  |  |  |  |  | 4
 |  |  | 0603 RC0603FR-0722RL
 | Подп. и дата | 25 | 36kOhm 5% 75В 0.1Вт 155°C |  |  | Yageo |  |  |  |  |  |  |  | 1
 |  |  | 0603 RC0603JR-0736KL Yageo
 |  | 26 | 4.7kOhm 5% 75В 0.1Вт 155°C |  |  | Yageo |  |  |  |  |  |  |  | 5
 |  |  | 0603 RC0603JR-074K7L Yageo
 | Инв. № дубл. | 27 | 510Ohm 1% 50В 0.063Вт 155°C |  |  |  |  |  |  |  |  |  |  | 1
 |  |  | 0603 RC0603FR-07510RL
 | Взам. инв. № |  | Переключатели
 |  | 28 | Выключатель кнопочный |  |  |  |  |  |  |  |  |  |  | 2
 |  |  | нажимной KAN0641-0431B
 | Подп. и дата
 |  |  | Приборы электровакуумные
 |  |  | и полупроводниковые
 | Инв. № подл.
 |  |  |  |  |  |  |  |  |  |  |  |  | МИЭМ.467999.001 ВП |  |  |  |  |  | Лист
 |  |  |  |  |  |  |  |  |  |  |  |  |  |  |  |  |  |  | 3
 |  |  |  |  |  |  | Изм. | Лист | № докум. |  | Подп. | Дата

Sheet: 4
 |  | № строки | Наименование | Код продукции | Обозначение документа на поставку | Поставщик |  |  |  | Куда входит (обозначение) |  |  |  | Количество |  |  |  | Примечание
-00 |  |  |  |  |  |  |  |  |  |  |  |  |  | На изделие | В комп-екты | На ре-гулир. | Всего
 |  |  | Приборы электровакуумные
 |  |  | и полупроводниковые
 |  | 29 | Диод светоизлучающий Зеленый |  |  | Ningbo Foryard |  |  |  |  |  |  |  | 4
 |  |  | 0603 FYLS-0603PGC Ningbo |  |  | Optoelectronics
 |  |  | Foryard Optoelectronics
 |  |  | Диоды
 |  | 30 | Диод Шоттки 10В 125°C |  |  | STMicroelectronics |  |  |  |  |  |  |  | 3
 |  |  | SOD-323 STMicroelectronics
 |  | 31 | Диод Шоттки 30В 150°C SMA |  |  | STMicroelectronics |  |  |  |  |  |  |  | 1
 |  |  | STMicroelectronics
 |  |  | Транзисторы
 |  | 32 | MOSFET 30В 2.5Вт 150°C SO-8 |  |  | STMicroelectronics |  |  |  |  |  |  |  | 1
 |  |  | STS7PF30L STMicroelectronics
 |  | 33 | NPN 40В 0.3Вт 150°C SOT-23-3 |  |  | Hottech |  |  |  |  |  |  |  | 1
 | Подп. и дата |  | S9013 Hottech
 |  |  | Соединения контактные
 |  | 34 | Разъем mini-USB на плату SMD |  |  |  |  |  |  |  |  |  |  | 1
 | Инв. № дубл. |  | 1734035-1
 |  | 35 | Соединение контактное PLS_2 |  |  |  |  |  |  |  |  |  |  | 1
 |  | 36 | Соединение контактное PLS_3 |  |  |  |  |  |  |  |  |  |  | 1
 | Взам. инв. №
 |  |  | Вилки
 |  | 37 | Соединение контактное PLS_10 |  |  |  |  |  |  |  |  |  |  | 1
 | Подп. и дата | 38 | Соединение контактное |  |  |  |  |  |  |  |  |  |  | 2
 |  |  | PLS_19x2
 |  | 39 | Соединение контактное PLS_2 |  |  |  |  |  |  |  |  |  |  | 4
 |  | 40 | Соединение контактное PLS_4 |  |  |  |  |  |  |  |  |  |  | 1
 | Инв. № подл. | 41 | Соединение контактное PLS_6 |  |  |  |  |  |  |  |  |  |  | 2
 |  |  |  |  |  |  |  |  |  |  |  |  | МИЭМ.467999.001 ВП |  |  |  |  |  | Лист
 |  |  |  |  |  |  |  |  |  |  |  |  |  |  |  |  |  |  | 4
 |  |  |  |  |  |  | Изм. | Лист | № докум. |  | Подп. | Дата

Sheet: 5
 |  | № строки | Наименование | Код продукции | Обозначение документа на поставку | Поставщик |  |  |  | Куда входит (обозначение) |  |  |  | Количество |  |  |  | Примечание
-00 |  |  |  |  |  |  |  |  |  |  |  |  |  | На изделие | В комп-екты | На ре-гулир. | Всего
 |  |  | Вилки
 |  | 42 | Соединение контактное PLS_8 |  |  |  |  |  |  |  |  |  |  | 2
 | Подп. и дата
 | Инв. № дубл.
 | Взам. инв. №
 | Подп. и дата
 | Инв. № подл.
 |  |  |  |  |  |  |  |  |  |  |  |  | МИЭМ.467999.001 ВП |  |  |  |  |  | Лист
 |  |  |  |  |  |  |  |  |  |  |  |  |  |  |  |  |  |  | 5
 |  |  |  |  |  |  | Изм. | Лист | № докум. |  | Подп. | Дата

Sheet: Лист регистрации изменений.
 | Лист регистрации изменений
 | Изм. |  | Номера листов (страниц) |  |  |  |  |  |  |  | Всего листов (страниц) в докум. | № докум. | Входящий № сопроводи- тельного документа и дата | Под- пись | Дата
 |  |  | изме- ненных |  | заме- няемых |  | новых |  |  | аннули-рованных
Подп. и дата
Инв. № дубл.
Взам. инв. №
Подп. и дата
Инв.№ подл.
 |  |  |  |  |  |  |  |  | МИЭМ.467999.001 ВП |  |  |  |  |  |  | Лист
 |  |  |  |  |  |  |  |  |  |  |  |  |  |  |  | 6
 | Изм. | Лист |  | № докум |  | Подп. |  | Дата

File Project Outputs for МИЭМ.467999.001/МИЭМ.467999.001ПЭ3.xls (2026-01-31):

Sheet: МИЭМ.467999.001. Первый лист.
Перв. примен. | МИЭМ.467999.001 | Поз. обозна-чение |  |  | Наименование |  |  |  | Кол. |  | Примечание
 |  |  |  |  | Конденсаторы
 |  | C1 |  |  | 100nF 10% 100В 125°C 0603 CC0603KRX7R0BB104 Yageo |  |  |  | 1
 |  | C2 |  |  | 1uF 10% 10В 85°C 0603 GRM185R61A105K Murata Electronics |  |  |  | 1
Справ. № |  | C3 |  |  | 20pF 5% 50В 125°C 0603 GRM1885C1H200J Murata |  |  |  | 1
 |  |  |  |  | Electronics
 |  | C4-C7 |  |  | 100nF 10% 100В 125°C 0603 CC0603KRX7R0BB104 Yageo |  |  |  | 4
 |  | C8 |  |  | 20pF 5% 50В 125°C 0603 GRM1885C1H200J Murata |  |  |  | 1
 |  |  |  |  | Electronics
 |  | C9 |  |  | 10nF 10% 100В 125°C 0603 CC0603KRX7R0BB103 Yageo |  |  |  | 1
 |  | C11,C12 |  |  | 100nF 10% 100В 125°C 0603 CC0603KRX7R0BB104 Yageo |  |  |  | 2
 |  | C13 |  |  | 1uF 10% 10В 85°C 0603 GRM185R61A105K Murata Electronics |  |  |  | 1
 |  | C14,C15 |  |  | 100nF 10% 100В 125°C 0603 CC0603KRX7R0BB104 Yageo |  |  |  | 2
 |  | C16,C17 |  |  | 10uF 10% 25В 125℃ 1411 TAJB106K025RNJ Kyocera AVX |  |  |  | 2
Подп. и дата |  | C18 |  |  | 1uF 10% 10В 85°C 0603 GRM185R61A105K Murata Electronics |  |  |  | 1
 |  | C19,C20 |  |  | 100nF 10% 100В 125°C 0603 CC0603KRX7R0BB104 Yageo |  |  |  | 2
 |  | C21 |  |  | 1uF 10% 10В 85°C 0603 GRM185R61A105K Murata Electronics |  |  |  | 1
 |  | C23,C24 |  |  | 100nF 10% 100В 125°C 0603 CC0603KRX7R0BB104 Yageo |  |  |  | 2
Инв. № дубл. |  | C27,C28 |  |  | 100nF 10% 100В 125°C 0603 CC0603KRX7R0BB104 Yageo |  |  |  | 2
 |  | C29 |  |  | 1uF 10% 10В 85°C 0603 GRM185R61A105K Murata Electronics |  |  |  | 1
 |  | C30 |  |  | 100nF 10% 100В 125°C 0603 CC0603KRX7R0BB104 Yageo |  |  |  | 1
Взам. инв.№ |  | C31,C32 |  |  | 4.3pF 1% 50В 125°C 0603 CC0603CRNPO9BN4R3 Yageo |  |  |  | 2
 |  | C33,C34 |  |  | 20pF 5% 50В 155°C 0603 GRM1885C1H200J Murata |  |  |  | 2
 |  |  |  |  | Electronics
Подп. и дата
 |  |  |  |  |  |  |  | МИЭМ.467999.001ПЭ3
 |  | Изм. | Лист | № докум. |  | Подп. | Дата
Инв. № подл. |  | Разраб. |  | Бадалян |  |  |  | Плата отладочная |  | Лит. |  | Лист | Листов
 |  | Пров. |  |  |  |  |  |  |  | У |  | 1 | 6
 |  | Вед. Инж. |  | Бадалян |  |  |  |  |  | МИЭМ
 |  | Н.контр
 |  | Утв. |  |  |  |  |  | Перечень элементов

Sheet: 2
 | Поз. обозна- чение |  |  | Наименование |  |  |  | Кол. | Примечание
 |  |  |  | Микросхемы
 | DA1 |  |  | Стабилизатор напряжения линейный 6 В 125 °C SOT-23-5 |  |  |  | 1
 |  |  |  | STMicroelectronics
 | DA3 |  |  | табилизатор напряжения 15 В 150 °C SOT-223 |  |  |  | 1
 |  |  |  | STMicroelectronics
 | DA4 |  |  | Стабилизатор напряжения линейный 5.5 В 125 °C DFN6 (3x3 |  |  |  | 1
 |  |  |  | mm) STMicroelectronics
 | DD2 |  |  | Микроконтроллер 32-Бит 72МГц 85°C LQFP-48 STM32F103CBT6 |  |  |  | 1
 |  |  |  | STMicroelectronics
 | DD5 |  |  | Микроконтроллер ARM 48МГц 85°C LQFP64-10x10 |  |  |  | 1
 |  |  |  | STM32F030R8T6 STMicroelectronics
 |  |  |  | Элементы защиты по току
Подп. и дата
 | FA1 |  |  | Сердечник ферритовый 500мА 0603 FCM1608KF-601T05 |  |  |  | 1
 |  |  |  | Генераторы
Инв. № дубл.
 | G1 |  |  | Осциллятор кварцевый 70°С HC 49SMD |  |  |  | 1
 | G2 |  |  | Осциллятор кварцевый 0.002% 85°C QSMD8x3.8 |  |  |  | 1
Взам. инв.№ |  |  |  | ABS25-32.768KHZ-6-T
 | G3 |  |  | Осциллятор кварцевый 70°С HC49SMD |  |  |  | 1
Подп. и дата |  |  |  | Резисторы
 | R1,R3 |  |  | 10kOhm 1% 50В 0.1Вт 155°C 0603 RC0603FR-0710KL |  |  |  | 2
 | R4 |  |  | 4.7kOhm 5% 75В 0.1Вт 155°C 0603 RC0603JR-074K7L Yageo |  |  |  | 1
 | R5 |  |  | 22Ohm 1% 50В 0.1Вт 155°C 0603 RC0603FR-0722RL |  |  |  | 1
Инв. № подл. | R6 |  |  | 100kOhm 1% 75В 0.1Вт 155°C 0603 0603WAF1003T5E |  |  |  | 1
 |  |  |  | UNI-ROYAL(Uniroyal Elec)
 |  |  |  |  |  |  | МИЭМ.467999.001ПЭ3 |  |  | Лист
 |  |  |  |  |  |  |  |  |  | 2
 | Изм. | Лист | № докум. |  | Подп. | Дата

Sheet: 3
 | Поз. обозна- чение |  |  | Наименование |  |  |  | Кол. | Примечание
 |  |  |  | Резисторы
 | R7 |  |  | 2.7kOhm 5% 75В 0.1Вт 155°C 0603 RC0603JR-072K7L Yageo |  |  |  | 1
 | R8 |  |  | 22Ohm 1% 50В 0.1Вт 155°C 0603 RC0603FR-0722RL |  |  |  | 1
 | R10 |  |  | 36kOhm 5% 75В 0.1Вт 155°C 0603 RC0603JR-0736KL Yageo |  |  |  | 1
 | R11 |  |  | 100Ohm 1% 75В 0.1Вт 155°C 0603 AC0603FR-07100RL Yageo |  |  |  | 1
 | R12 |  |  | 10kOhm 1% 50В 0.1Вт 155°C 0603 RC0603FR-0710KL |  |  |  | 1
 | R13 |  |  | 22Ohm 1% 50В 0.1Вт 155°C 0603 RC0603FR-0722RL |  |  |  | 1
 | R14,R15 |  |  | 100kOhm 1% 75В 0.1Вт 155°C 0603 0603WAF1003T5E |  |  |  | 2
 |  |  |  | UNI-ROYAL(Uniroyal Elec)
 | R16 |  |  | 1.5kOhm 1% 50В 0.1Вт 155°C 0603 RC0603FR-071K5L |  |  |  | 1
 | R17-R19 |  |  | 0 1% 75В 0.1Вт 155°C 0603 RC0603FR-070RL Yageo |  |  |  | 3
 | R20,R21 |  |  | 100Ohm 1% 75В 0.1Вт 155°C 0603 AC0603FR-07100RL Yageo |  |  |  | 2
 | R22 |  |  | 22Ohm 1% 50В 0.1Вт 155°C 0603 RC0603FR-0722RL |  |  |  | 1
Подп. и дата | R23 |  |  | 4.7kOhm 5% 75В 0.1Вт 155°C 0603 RC0603JR-074K7L Yageo |  |  |  | 1
 | R24,R25 |  |  | 100Ohm 1% 75В 0.1Вт 155°C 0603 AC0603FR-07100RL Yageo |  |  |  | 2
 | R27,R28 |  |  | 4.7kOhm 5% 75В 0.1Вт 155°C 0603 RC0603JR-074K7L Yageo |  |  |  | 2
 | R29 |  |  | 100Ohm 1% 75В 0.1Вт 155°C 0603 AC0603FR-07100RL Yageo |  |  |  | 1
Инв. № дубл. | R30 |  |  | 4.7kOhm 5% 75В 0.1Вт 155°C 0603 RC0603JR-074K7L Yageo |  |  |  | 1
 | R31 |  |  | 510Ohm 1% 50В 0.063Вт 155°C 0603 RC0603FR-07510RL |  |  |  | 1
 | R32 |  |  | 1kOhm 0.5% 50В 0.1Вт 155°C 0603 RP0603DRD071KL Yageo |  |  |  | 1
Взам. инв.№ | R33 |  |  | 10kOhm 1% 50В 0.1Вт 155°C 0603 RC0603FR-0710KL |  |  |  | 1
 | R34-R37 |  |  | 0 1% 75В 0.1Вт 155°C 0603 RC0603FR-070RL Yageo |  |  |  | 4
Подп. и дата |  |  |  | Переключатели
 | SA1,SA2 |  |  | Выключатель кнопочный нажимной KAN0641-0431B |  |  |  | 2
Инв. № подл.
 |  |  |  |  |  |  | МИЭМ.467999.001ПЭ3 |  |  | Лист
 |  |  |  |  |  |  |  |  |  | 3
 | Изм. | Лист | № докум. |  | Подп. | Дата

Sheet: 4
 | Поз. обозна- чение |  |  | Наименование |  |  |  | Кол. | Примечание
 |  |  |  | Выключатели кнопочные
 | SB3-SB10 |  |  | Перемычка |  |  |  | 8
 | SB12,SB15 |  |  | Перемычка |  |  |  | 2
 | SB45,SB60 |  |  | Перемычка |  |  |  | 2
 |  |  |  | Приборы электровакуумные и полупроводниковые
 | V2,V3 |  |  | Диод светоизлучающий Зеленый 0603 FYLS-0603PGC Ningbo |  |  |  | 2
 |  |  |  | Foryard Optoelectronics
 | V11,V12 |  |  | Диод светоизлучающий Зеленый 0603 FYLS-0603PGC Ningbo |  |  |  | 2
 |  |  |  | Foryard Optoelectronics
 |  |  |  | Диоды
Подп. и дата
 | VD1-VD3 |  |  | Диод Шоттки 10В 125°C SOD-323 STMicroelectronics |  |  |  | 3
 | VD4 |  |  | Диод Шоттки 30В 150°C SMA STMicroelectronics |  |  |  | 1
Инв. № дубл. |  |  |  | Транзисторы
 | VT1 |  |  | NPN 40В 0.3Вт 150°C SOT-23-3 S9013 Hottech |  |  |  | 1
Взам. инв.№ | VT2 |  |  | MOSFET 30В 2.5Вт 150°C SO-8 STS7PF30L |  |  |  | 1
 |  |  |  | STMicroelectronics
Подп. и дата |  |  |  | Соединения контактные
 | X1 |  |  | Разъем mini-USB на плату SMD 1734035-1 |  |  |  | 1
 | X5 |  |  | Соединение контактное PLS_3 |  |  |  | 1
 | X6 |  |  | Соединение контактное PLS_2 |  |  |  | 1
Инв. № подл.
 |  |  |  |  |  |  | МИЭМ.467999.001ПЭ3 |  |  | Лист
 |  |  |  |  |  |  |  |  |  | 4
 | Изм. | Лист | № докум. |  | Подп. | Дата

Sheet: 5
 | Поз. обозна- чение |  |  | Наименование |  |  |  | Кол. | Примечание
 |  |  |  | Вилки
 | XP1 |  |  | Соединение контактное PLS_2 |  |  |  | 1
 | XP2 |  |  | Соединение контактное PLS_4 |  |  |  | 1
 | XP3 |  |  | Соединение контактное PLS_2 |  |  |  | 1
 | XP4 |  |  | Соединение контактное PLS_6 |  |  |  | 1
 | XP5 |  |  | Соединение контактное PLS_10 |  |  |  | 1
 | XP6 |  |  | Соединение контактное PLS_8 |  |  |  | 1
 | XP7 |  |  | Соединение контактное PLS_19x2 |  |  |  | 1
 | XP8 |  |  | Соединение контактное PLS_6 |  |  |  | 1
 | XP9 |  |  | Соединение контактное PLS_8 |  |  |  | 1
 | XP10 |  |  | Соединение контактное PLS_19x2 |  |  |  | 1
 | XP11,XP12 |  |  | Соединение контактное PLS_2 |  |  |  | 2
Подп. и дата
Инв. № дубл.
Взам. инв.№
Подп. и дата
Инв. № подл.
 |  |  |  |  |  |  | МИЭМ.467999.001ПЭ3 |  |  | Лист
 |  |  |  |  |  |  |  |  |  | 5
 | Изм. | Лист | № докум. |  | Подп. | Дата

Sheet: Лист регистрации изменений.
 | Лист регистрации изменений
 | Изм. |  | Номера листов (страниц) |  |  |  |  |  |  |  | Всего листов (страниц) в докум. | № докум. | Входящий № сопроводи-тельного документа и дата | Под- пись | Дата
 |  |  | изменен- ных |  | заменен- ных |  | новых |  |  | аннули- рован- ных
Подп. и дата
Инв. № дубл.
Взам. инв.№
Подп. и дата
Инв. № подл.
 |  |  |  |  |  |  |  |  | МИЭМ.467999.001ПЭ3 |  |  |  |  |  |  | Лист
 |  |  |  |  |  |  |  |  |  |  |  |  |  |  |  | 6
 | Изм. | Лист |  | № докум. |  | Подп. |  | Дата

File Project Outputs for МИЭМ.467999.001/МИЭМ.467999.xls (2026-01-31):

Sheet: МИЭМ.467999.001. Первый лист.
Перв. примен. | Формат | Зона |  | Поз. |  | Обозначение |  |  |  | Наименование |  |  | Кол. | Примечание
 |  |  |  |  |  |  |  |  |  | Документация
 | А3 |  |  |  |  | МИЭМ.467999.001Э3 |  |  |  | Схема электрическая
 |  |  |  |  |  |  |  |  |  | принципиальная
 | А4 |  |  |  |  | МИЭМ.467999.001ПЭ3 |  |  |  | Перечень элементов
Справ. № | А3 |  |  |  |  | МИЭМ.467999.001ВП |  |  |  | Ведомость покупных изделий
 | А3 |  |  |  |  | МИЭМ.467999.001СБ |  |  |  | Сборочный чертеж
 |  |  |  |  |  |  |  |  |  | Сборочные единицы
 | А3 |  |  | 1 |  | МИЭМ.687253.001 |  |  |  | Плата печатная |  |  | 1
 |  |  |  |  |  |  |  |  |  | Прочие изделия
 |  |  |  |  |  |  |  |  |  | Конденсаторы
 |  |  |  | 2 |  |  |  |  |  | 100nF 10% 100В 125°C 0603 |  |  | 16 | C1, C4-C7,
Подп. и дата |  |  |  |  |  |  |  |  |  | CC0603KRX7R0BB104 Yageo |  |  |  | C11, C12, C14,
 |  |  |  |  |  |  |  |  |  |  |  |  |  | C15, C19, C20,
 |  |  |  |  |  |  |  |  |  |  |  |  |  | C23, C24, C27,
 |  |  |  |  |  |  |  |  |  |  |  |  |  | C28, C30
Инв. № дубл. |  |  |  | 3 |  |  |  |  |  | 10nF 10% 100В 125°C 0603 |  |  | 1 | C9
 |  |  |  |  |  |  |  |  |  | CC0603KRX7R0BB103 Yageo
 |  |  |  | 4 |  |  |  |  |  | 10uF 10% 25В 125℃ 1411 |  |  | 2 | C16, C17
Взам. инв. № |  |  |  |  |  |  |  |  |  | TAJB106K025RNJ Kyocera AVX
Подп. и дата
 |  |  |  |  |  |  |  |  | МИЭМ.467999.001
 | Изм. |  | Лист |  | № докум. |  | Подп. | Дата
Инв. № подл. | Разраб. |  |  |  | Бадалян |  |  |  | Плата отладочная |  | Лит. | Лист |  |  | Листов
 | Пров. |  |  |  |  |  |  |  |  |  | У | 1 |  |  | 7
 | Вед. Инж. |  |  |  | Бадалян
 | Н. контр.
 | Утв.

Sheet: 2
 | Формат | Зона |  | Поз. |  | Обозначение |  |  |  | Наименование | Кол. | Примечание
 |  |  |  |  |  |  |  |  |  | Конденсаторы
 |  |  |  | 5 |  |  |  |  |  | 1uF 10% 10В 85°C 0603 | 5 | C2, C13, C18,
 |  |  |  |  |  |  |  |  |  | GRM185R61A105K Murata |  | C21, C29
 |  |  |  |  |  |  |  |  |  | Electronics
 |  |  |  | 6 |  |  |  |  |  | 20pF 5% 50В 125°C 0603 | 2 | C3, C8
 |  |  |  |  |  |  |  |  |  | GRM1885C1H200J Murata
 |  |  |  |  |  |  |  |  |  | Electronics
 |  |  |  | 7 |  |  |  |  |  | 20pF 5% 50В 155°C 0603 | 2 | C33, C34
 |  |  |  |  |  |  |  |  |  | GRM1885C1H200J Murata
 |  |  |  |  |  |  |  |  |  | Electronics
 |  |  |  | 8 |  |  |  |  |  | 4.3pF 1% 50В 125°C 0603 | 2 | C31, C32
 |  |  |  |  |  |  |  |  |  | CC0603CRNPO9BN4R3 Yageo
 |  |  |  |  |  |  |  |  |  | Микросхемы
 |  |  |  | 9 |  |  |  |  |  | Микроконтроллер 32-Бит | 1 | DD2
 |  |  |  |  |  |  |  |  |  | 72МГц 85°C LQFP-48
 |  |  |  |  |  |  |  |  |  | STM32F103CBT6
Подп. и дата |  |  |  |  |  |  |  |  |  | STMicroelectronics
 |  |  |  | 10 |  |  |  |  |  | Микроконтроллер ARM 48МГц | 1 | DD5
 |  |  |  |  |  |  |  |  |  | 85°C LQFP64-10x10
 |  |  |  |  |  |  |  |  |  | STM32F030R8T6
Инв. № дубл. |  |  |  |  |  |  |  |  |  | STMicroelectronics
 |  |  |  | 11 |  |  |  |  |  | Стабилизатор напряжения | 1 | DA4
 |  |  |  |  |  |  |  |  |  | линейный 5.5 В 125 °C DFN6
Взам. инв. № |  |  |  |  |  |  |  |  |  | (3x3 mm)
 |  |  |  |  |  |  |  |  |  | STMicroelectronics
 |  |  |  | 12 |  |  |  |  |  | Стабилизатор напряжения | 1 | DA1
Подп. и дата |  |  |  |  |  |  |  |  |  | линейный 6 В 125 °C
 |  |  |  |  |  |  |  |  |  | SOT-23-5
 |  |  |  |  |  |  |  |  |  | STMicroelectronics
Инв. № подл.
 |  |  |  |  |  |  |  |  | МИЭМ.467999.001 |  |  |  | Лист
 |  |  |  |  |  |  |  |  |  |  |  |  | 2
 | Изм. |  | Лист |  | № докум. |  | Подп. | Дата

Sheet: 3
 | Формат | Зона |  | Поз. |  | Обозначение |  |  |  | Наименование | Кол. | Примечание
 |  |  |  |  |  |  |  |  |  | Микросхемы
 |  |  |  | 13 |  |  |  |  |  | табилизатор напряжения 15 | 1 | DA3
 |  |  |  |  |  |  |  |  |  | В 150 °C SOT-223
 |  |  |  |  |  |  |  |  |  | STMicroelectronics
 |  |  |  |  |  |  |  |  |  | Элементы защиты по току
 |  |  |  | 14 |  |  |  |  |  | Сердечник ферритовый 500мА | 1 | FA1
 |  |  |  |  |  |  |  |  |  | 0603 FCM1608KF-601T05
 |  |  |  |  |  |  |  |  |  | Генераторы
 |  |  |  | 15 |  |  |  |  |  | Осциллятор кварцевый | 1 | G2
 |  |  |  |  |  |  |  |  |  | 0.002% 85°C QSMD8x3.8
 |  |  |  |  |  |  |  |  |  | ABS25-32.768KHZ-6-T
 |  |  |  | 16 |  |  |  |  |  | Осциллятор кварцевый 70°С | 1 | G3
 |  |  |  |  |  |  |  |  |  | HC49SMD
 |  |  |  | 17 |  |  |  |  |  | Осциллятор кварцевый 70°С | 1 | G1
 |  |  |  |  |  |  |  |  |  | HC 49SMD
Подп. и дата
 |  |  |  |  |  |  |  |  |  | Резисторы
 |  |  |  | 18 |  |  |  |  |  | 0 1% 75В 0.1Вт 155°C 0603 | 7 | R17-R19,
 |  |  |  |  |  |  |  |  |  | RC0603FR-070RL Yageo |  | R34-R37
Инв. № дубл. |  |  |  | 19 |  |  |  |  |  | 1.5kOhm 1% 50В 0.1Вт 155°C | 1 | R16
 |  |  |  |  |  |  |  |  |  | 0603 RC0603FR-071K5L
 |  |  |  | 20 |  |  |  |  |  | 100kOhm 1% 75В 0.1Вт 155°C | 3 | R6, R14, R15
Взам. инв. № |  |  |  |  |  |  |  |  |  | 0603 0603WAF1003T5E
 |  |  |  |  |  |  |  |  |  | UNI-ROYAL(Uniroyal Elec)
 |  |  |  | 21 |  |  |  |  |  | 100Ohm 1% 75В 0.1Вт 155°C | 6 | R11, R20, R21,
Подп. и дата |  |  |  |  |  |  |  |  |  | 0603 AC0603FR-07100RL |  | R24, R25, R29
 |  |  |  |  |  |  |  |  |  | Yageo
 |  |  |  | 22 |  |  |  |  |  | 10kOhm 1% 50В 0.1Вт 155°C | 4 | R1, R3, R12,
 |  |  |  |  |  |  |  |  |  | 0603 RC0603FR-0710KL |  | R33
Инв. № подл.
 |  |  |  |  |  |  |  |  | МИЭМ.467999.001 |  |  |  | Лист
 |  |  |  |  |  |  |  |  |  |  |  |  | 3
 | Изм. |  | Лист |  | № докум. |  | Подп. | Дата

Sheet: 4
 | Формат | Зона |  | Поз. |  | Обозначение |  |  |  | Наименование | Кол. | Примечание
 |  |  |  |  |  |  |  |  |  | Резисторы
 |  |  |  | 23 |  |  |  |  |  | 1kOhm 0.5% 50В 0.1Вт 155°C | 1 | R32
 |  |  |  |  |  |  |  |  |  | 0603 RP0603DRD071KL Yageo
 |  |  |  | 24 |  |  |  |  |  | 2.7kOhm 5% 75В 0.1Вт 155°C | 1 | R7
 |  |  |  |  |  |  |  |  |  | 0603 RC0603JR-072K7L Yageo
 |  |  |  | 25 |  |  |  |  |  | 22Ohm 1% 50В 0.1Вт 155°C | 4 | R5, R8, R13,
 |  |  |  |  |  |  |  |  |  | 0603 RC0603FR-0722RL |  | R22
 |  |  |  | 26 |  |  |  |  |  | 36kOhm 5% 75В 0.1Вт 155°C | 1 | R10
 |  |  |  |  |  |  |  |  |  | 0603 RC0603JR-0736KL Yageo
 |  |  |  | 27 |  |  |  |  |  | 4.7kOhm 5% 75В 0.1Вт 155°C | 5 | R4, R23, R27,
 |  |  |  |  |  |  |  |  |  | 0603 RC0603JR-074K7L Yageo |  | R28, R30
 |  |  |  | 28 |  |  |  |  |  | 510Ohm 1% 50В 0.063Вт | 1 | R31
 |  |  |  |  |  |  |  |  |  | 155°C 0603
 |  |  |  |  |  |  |  |  |  | RC0603FR-07510RL
 |  |  |  |  |  |  |  |  |  | Переключатели
 |  |  |  | 29 |  |  |  |  |  | Выключатель кнопочный | 2 | SA1, SA2
Подп. и дата |  |  |  |  |  |  |  |  |  | нажимной KAN0641-0431B
 |  |  |  |  |  |  |  |  |  | Выключатели кнопочные
 |  |  |  | 30 |  |  |  |  |  | Перемычка | 12 | SB3-SB10,
Инв. № дубл. |  |  |  |  |  |  |  |  |  |  |  | SB12, SB15,
 |  |  |  |  |  |  |  |  |  |  |  | SB45, SB60
Взам. инв. №
Подп. и дата
Инв. № подл.
 |  |  |  |  |  |  |  |  | МИЭМ.467999.001 |  |  |  | Лист
 |  |  |  |  |  |  |  |  |  |  |  |  | 4
 | Изм. |  | Лист |  | № докум. |  | Подп. | Дата

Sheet: 5
 | Формат | Зона |  | Поз. |  | Обозначение |  |  |  | Наименование | Кол. | Примечание
 |  |  |  |  |  |  |  |  |  | Приборы электровакуумные и
 |  |  |  |  |  |  |  |  |  | полупроводниковые
 |  |  |  | 31 |  |  |  |  |  | Диод светоизлучающий | 4 | V2, V3, V11,
 |  |  |  |  |  |  |  |  |  | Зеленый 0603 FYLS-0603PGC |  | V12
 |  |  |  |  |  |  |  |  |  | Ningbo Foryard
 |  |  |  |  |  |  |  |  |  | Optoelectronics
 |  |  |  |  |  |  |  |  |  | Диоды
 |  |  |  | 32 |  |  |  |  |  | Диод Шоттки 10В 125°C | 3 | VD1-VD3
 |  |  |  |  |  |  |  |  |  | SOD-323 STMicroelectronics
 |  |  |  | 33 |  |  |  |  |  | Диод Шоттки 30В 150°C SMA | 1 | VD4
 |  |  |  |  |  |  |  |  |  | STMicroelectronics
 |  |  |  |  |  |  |  |  |  | Транзисторы
 |  |  |  | 34 |  |  |  |  |  | MOSFET 30В 2.5Вт 150°C | 1 | VT2
 |  |  |  |  |  |  |  |  |  | SO-8 STS7PF30L
 |  |  |  |  |  |  |  |  |  | STMicroelectronics
Подп. и дата |  |  |  | 35 |  |  |  |  |  | NPN 40В 0.3Вт 150°C | 1 | VT1
 |  |  |  |  |  |  |  |  |  | SOT-23-3 S9013 Hottech
 |  |  |  |  |  |  |  |  |  | Соединения контактные
Инв. № дубл. |  |  |  | 36 |  |  |  |  |  | Разъем mini-USB на плату | 1 | X1
 |  |  |  |  |  |  |  |  |  | SMD 1734035-1
 |  |  |  | 37 |  |  |  |  |  | Соединение контактное | 1 | X6
Взам. инв. № |  |  |  |  |  |  |  |  |  | PLS_2
 |  |  |  | 38 |  |  |  |  |  | Соединение контактное | 1 | X5
 |  |  |  |  |  |  |  |  |  | PLS_3
Подп. и дата
Инв. № подл.
 |  |  |  |  |  |  |  |  | МИЭМ.467999.001 |  |  |  | Лист
 |  |  |  |  |  |  |  |  |  |  |  |  | 5
 | Изм. |  | Лист |  | № докум. |  | Подп. | Дата

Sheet: 6
 | Формат | Зона |  | Поз. |  | Обозначение |  |  |  | Наименование | Кол. | Примечание
 |  |  |  |  |  |  |  |  |  | Вилки
 |  |  |  | 39 |  |  |  |  |  | Соединение контактное | 1 | XP5
 |  |  |  |  |  |  |  |  |  | PLS_10
 |  |  |  | 40 |  |  |  |  |  | Соединение контактное | 2 | XP7, XP10
 |  |  |  |  |  |  |  |  |  | PLS_19x2
 |  |  |  | 41 |  |  |  |  |  | Соединение контактное | 4 | XP1, XP3,
 |  |  |  |  |  |  |  |  |  | PLS_2 |  | XP11, XP12
 |  |  |  | 42 |  |  |  |  |  | Соединение контактное | 1 | XP2
 |  |  |  |  |  |  |  |  |  | PLS_4
 |  |  |  | 43 |  |  |  |  |  | Соединение контактное | 2 | XP4, XP8
 |  |  |  |  |  |  |  |  |  | PLS_6
 |  |  |  | 44 |  |  |  |  |  | Соединение контактное | 2 | XP6, XP9
 |  |  |  |  |  |  |  |  |  | PLS_8
Подп. и дата
Инв. № дубл.
Взам. инв. №
Подп. и дата
Инв. № подл.
 |  |  |  |  |  |  |  |  | МИЭМ.467999.001 |  |  |  | Лист
 |  |  |  |  |  |  |  |  |  |  |  |  | 6
 | Изм. |  | Лист |  | № докум. |  | Подп. | Дата

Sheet: Лист регистрации изменений.
 | Лист регистрации изменений
 | Изм. |  | Номера листов (страниц) |  |  |  |  |  |  |  | Всего листов (страниц) в докум. | № докум. | Входящий № сопроводи- тельного документа и дата | Под- пись | Дата
 |  |  | изме- ненных |  | заме- няемых |  | новых |  |  | аннули-рованных
Подп. и дата
Инв. № дубл.
Взам. инв. №
Подп. и дата
Инв.№ подл.
 |  |  |  |  |  |  |  |  | МИЭМ.467999.001 |  |  |  |  |  |  | Лист
 |  |  |  |  |  |  |  |  |  |  |  |  |  |  |  | 7
 | Изм. | Лист |  | № докум |  | Подп. |  | Дата

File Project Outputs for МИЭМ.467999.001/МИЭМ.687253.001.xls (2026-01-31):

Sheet: МИЭМ.687253.001. Первый лист.
Перв. примен. | МИЭМ.467999.001 | Формат | Зона |  | Поз. |  | Обозначение |  |  |  | Наименование |  |  | Кол. | Примечание
 |  |  |  |  |  |  |  |  |  |  | Документация
 |  | А3 |  |  |  |  | МИЭМ.687253.001СБ |  |  |  | Сборочный чертеж
 |  |  |  |  |  |  | МИЭМ.687253.001Т5М |  |  |  | Данные конструкции
 |  | А4 |  |  |  |  | МИЭМ.687253.001Д1 |  |  |  | Данные проектирования
Справ. № |  | А3
 |  | А3 |  |  |  |  |  |  |  |  | Материалы
 |  |  |  |  |  |  |  |  |  |  | Стеклоткань FR4 TG150 0,115 мм |  |  | 2 | Слои 1, 4
 |  |  |  |  |  |  |  |  |  |  | (Фольга 35 мкм)
 |  |  |  |  |  |  |  |  |  |  | Стеклотекстолит FR4 TG150 |  |  | 1 | Слои 2-3
 |  |  |  |  |  |  |  |  |  |  | (Фольга 35 мкм)
Подп. и дата
Инв. № дубл.
Взам. инв. №
Подп. и дата
 |  |  |  |  |  |  |  |  |  | МИЭМ.687253.001
 |  | Изм. |  | Лист |  | № докум. |  | Подп. | Дата
Инв. № подл. |  | Разраб. |  |  |  | Бадалян |  |  |  | Плата печатная многослойная |  | Лит. | Лист |  |  | Листов
 |  | Пров. |  |  |  |  |  |  |  |  |  | У | 1 |  |  | 2
 |  | Вед. Инж. |  |  |  | Бадалян
 |  | Н. контр.
 |  | Утв.

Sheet: Лист регистрации изменений.
 | Лист регистрации изменений
 | Изм. |  | Номера листов (страниц) |  |  |  |  |  |  |  | Всего листов (страниц) в докум. | № докум. | Входящий № сопроводи- тельного документа и дата | Под- пись | Дата
 |  |  | изме- ненных |  | заме- няемых |  | новых |  |  | аннули-рованных
Подп. и дата
Инв. № дубл.
Взам. инв. №
Подп. и дата
Инв.№ подл.
 |  |  |  |  |  |  |  |  | МИЭМ.467999.001 |  |  |  |  |  |  | Лист
 |  |  |  |  |  |  |  |  |  |  |  |  |  |  |  | 2
 | Изм. | Лист |  | № докум |  | Подп. |  | Дата

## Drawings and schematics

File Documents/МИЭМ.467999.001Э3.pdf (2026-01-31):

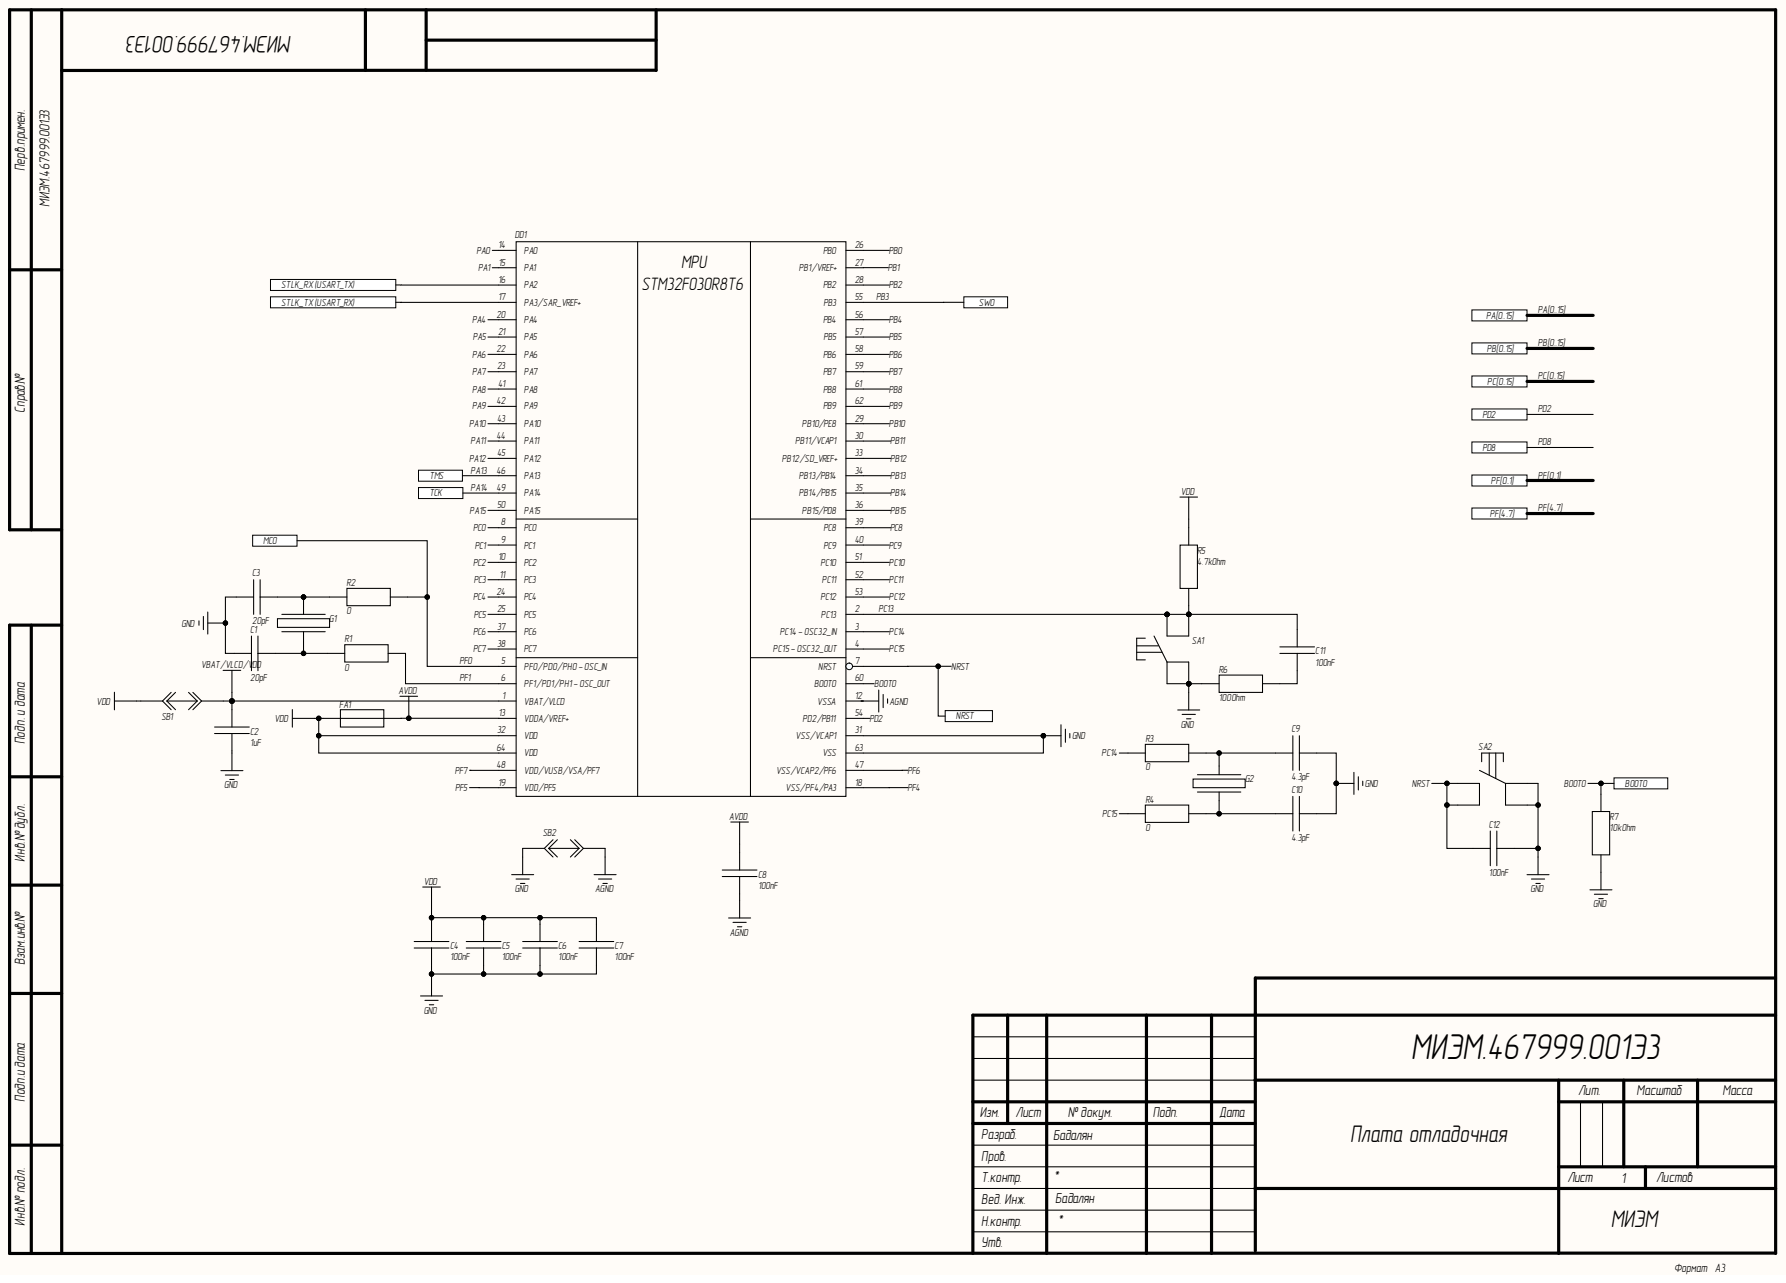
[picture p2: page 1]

P A0 P A1 P A2 P A3/S AR_ VREF+ P A4 P A5 P A6 P A7 P A8 P A9 P A10 P A11 P A12 P A13 P A14 P A15 | PB0 P B 1/VREF+ PB2 PB3 PB4 PB5 PB6 PB7 PB8 PB9 P B 1 0/PE8 P B 1 1/VCAP1 P B 1 2/S D_ VREF+ P B 1 3/PB14 P B 1 4/PB15 P B 1 5/PD8

PC0 PC1 PC2 PC3 PC4 PC5 PC6 PC7 | PC8 PC9 P C10 P C11 P C12 P C13 P C 1 4 -O S C 3 2_ IN P C 1 5 -O S C 3 2_ OUT

Инв.№ подл. Подп.и дата Взам.инв.№ Инв.№ дубл. Подп. и дата

32 | | 31
64 | | 63

Изм. | | № д о к у м . | Подп. | Дата | | Лист Лит.
нтр. Лист Разр аб.
Пров. | | Бадалян * *

Плата отладочная | | Масштаб | Масса

Т. к о | | | | | | Ли стов
Вед. Инж . | Бадалян | | | | МИЭМ
Н. к нтр.
Утв.

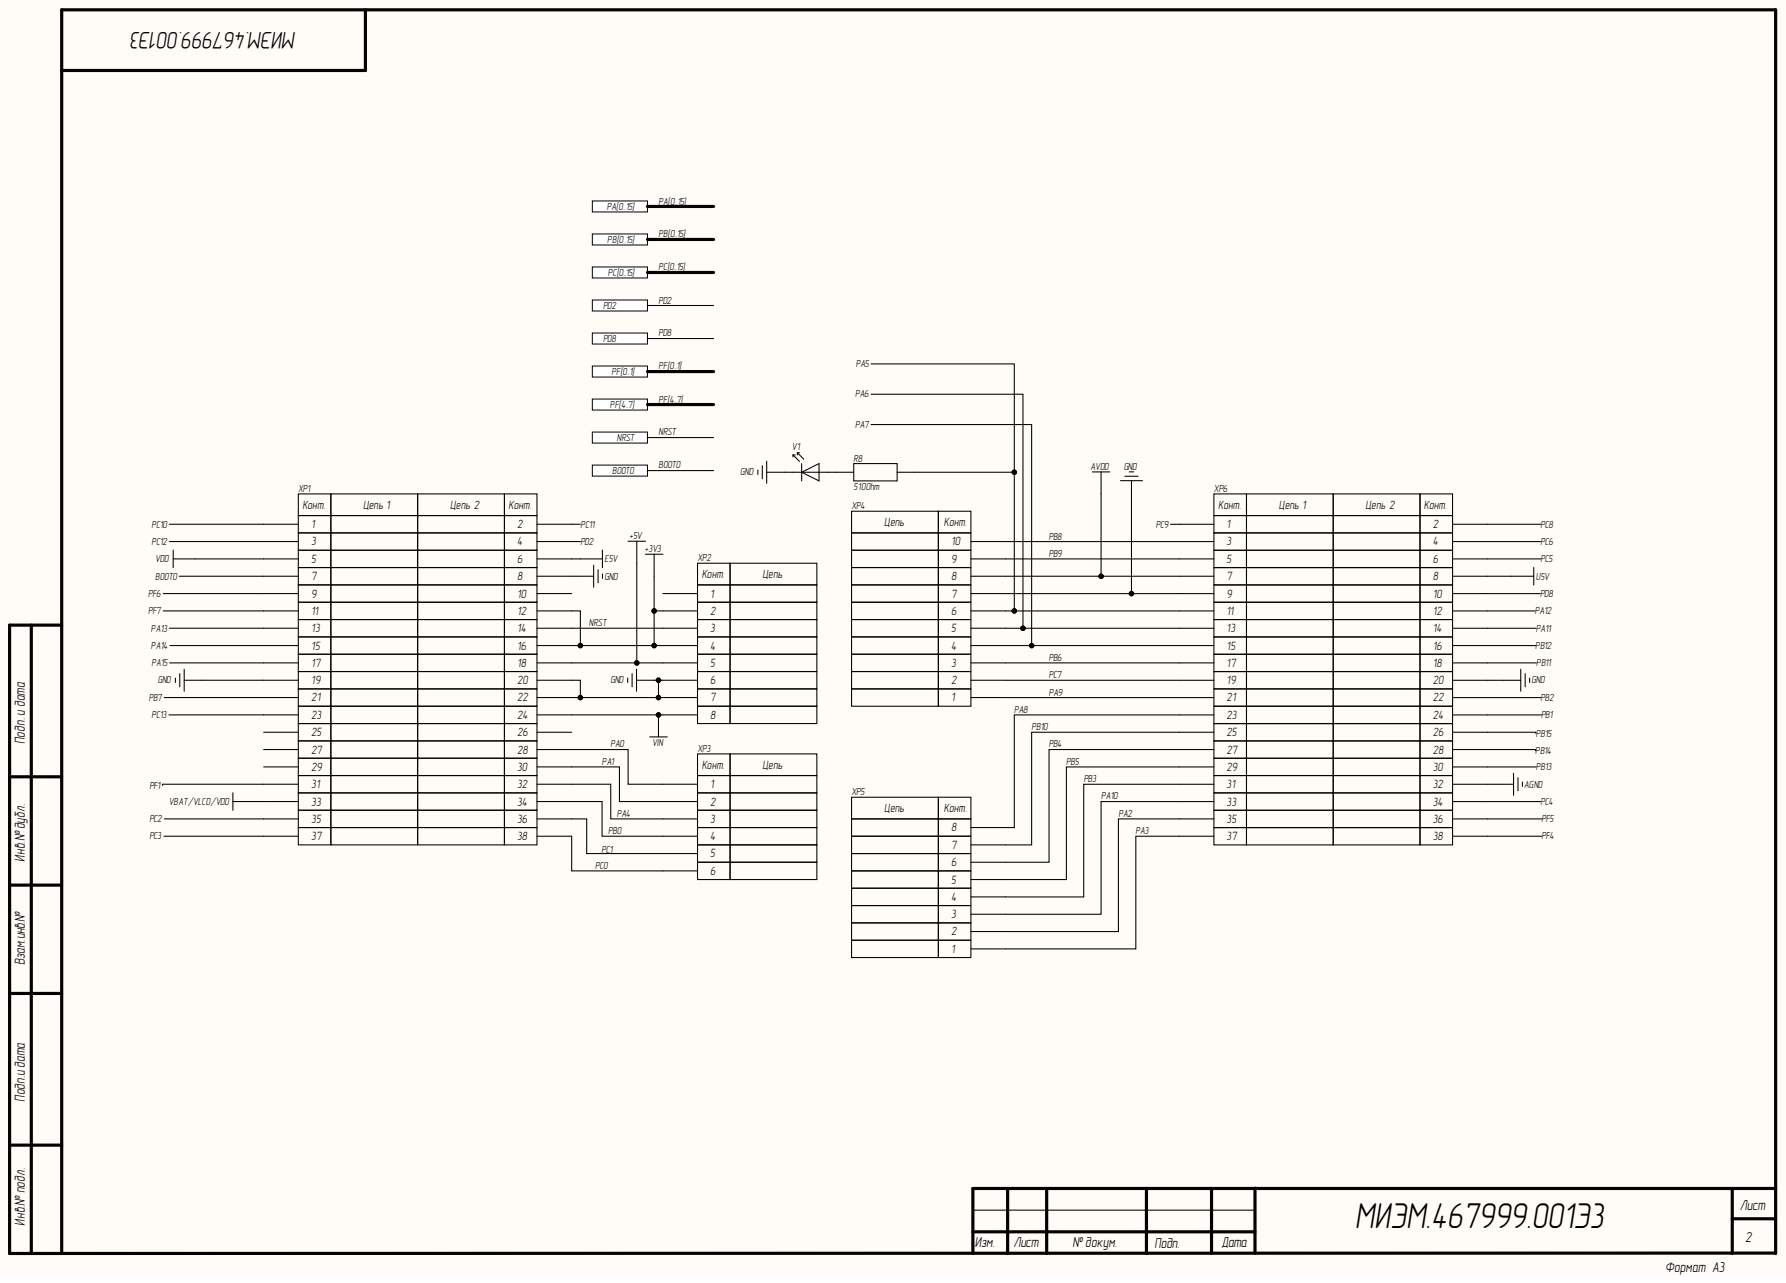
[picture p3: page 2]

PB3
P A10

Инв.№ подл. Подп.и дата Взам.инв.№ Инв.№ дубл.

PC1
PC0

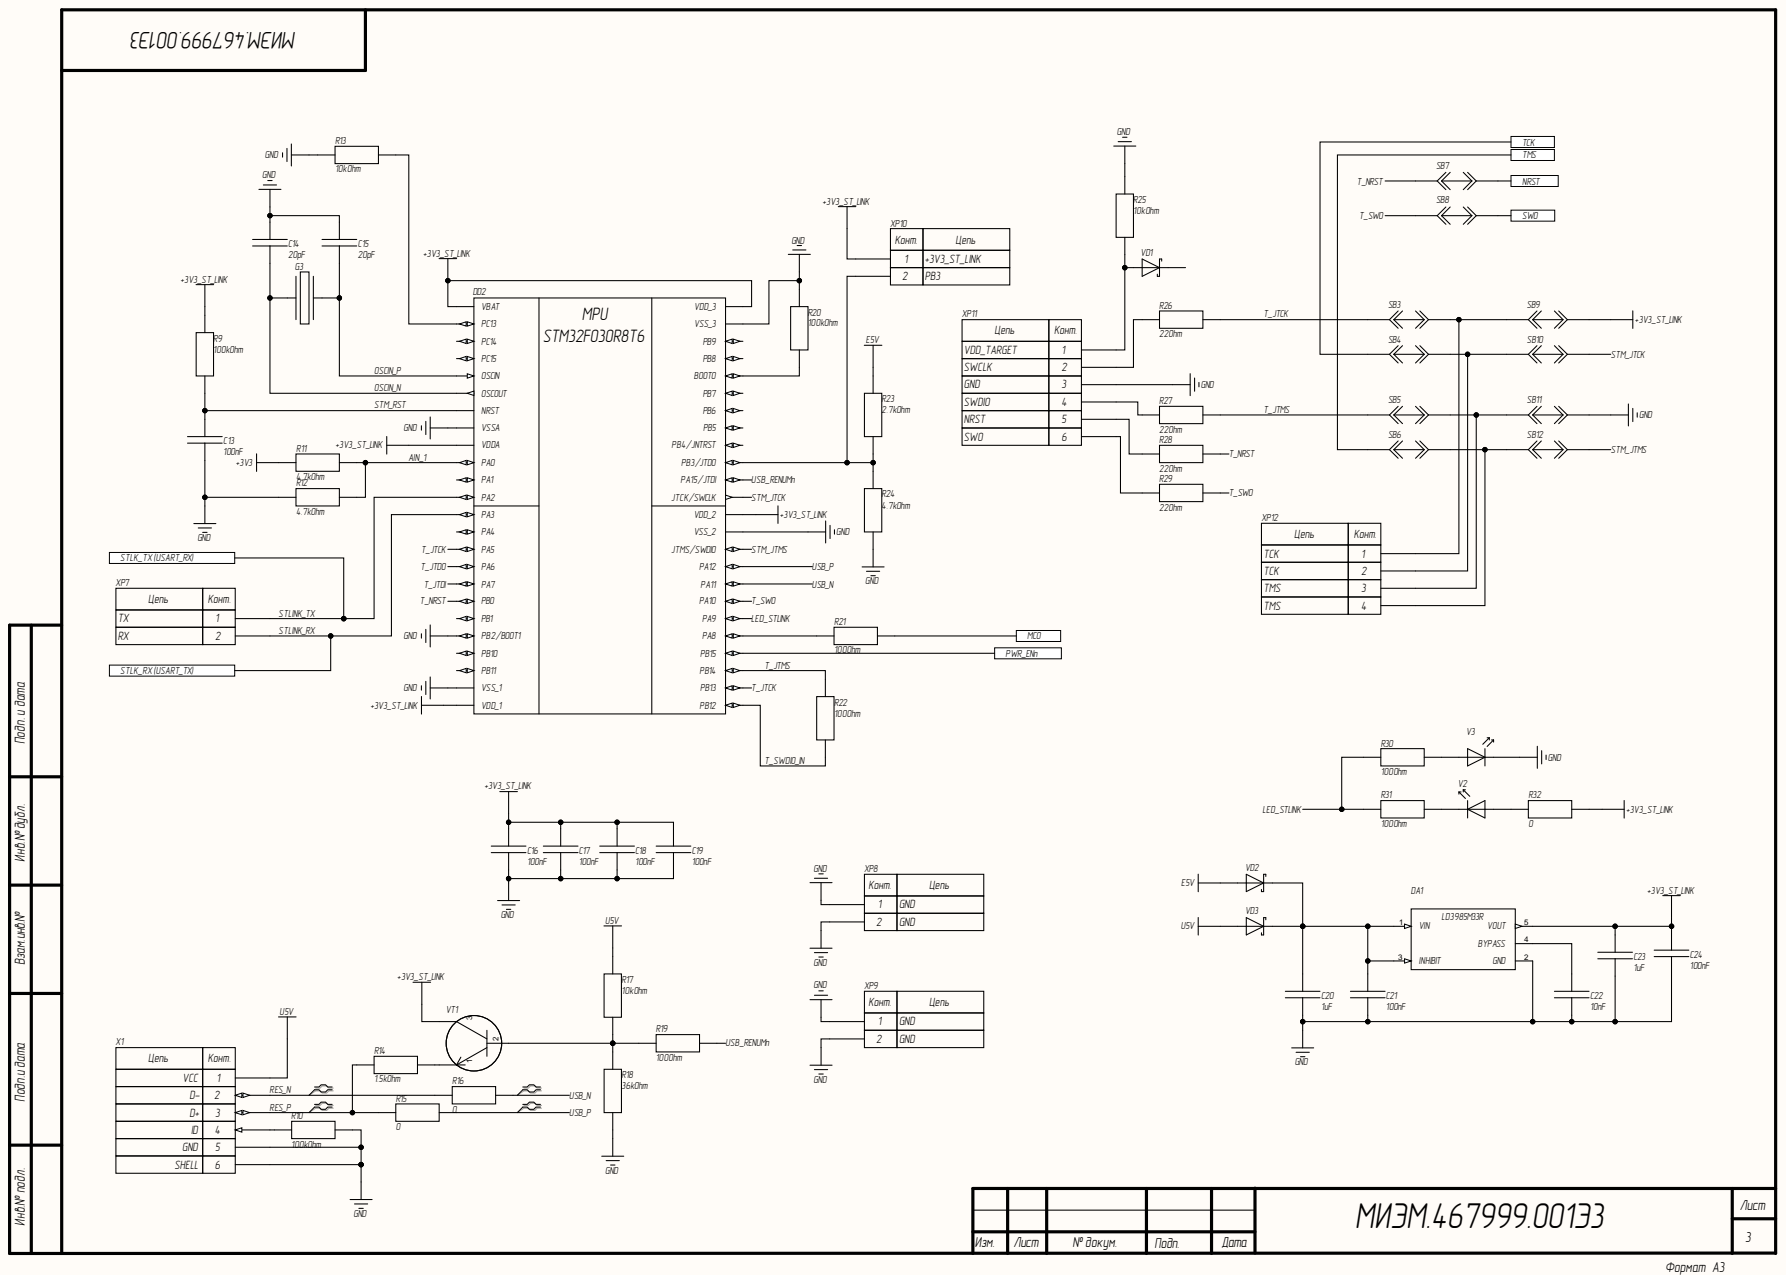
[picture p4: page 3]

SB7 T_NRST T_SWO | TMS

Конт. | Цепь
1 | +3V3_ST_LINK
2 | PB3

VDD_TARGET | 1
SWCLK | 2 | SB5 | SB11

NRST | 5 | | SB6 | SB12
SWO | 6 | 22Ohm R28

T_JTCK

TMS | 4

Инв.№ подл. Подп.и дата Взам.инв.№ Инв.№ дубл.

1 | GND
2 | GND

Цепь | Конт.

D- | 2
D+ | 3
ID | 4
GND | 5 | 100kOhm

RES_P | R15

МИЭМ.467999.001Э3 | 3

Изм. | № докум. | Дата

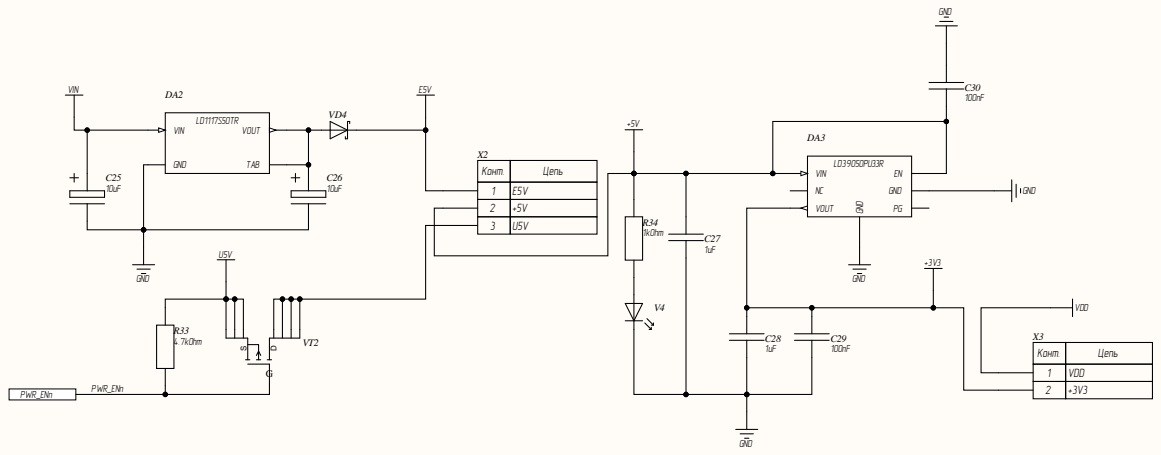
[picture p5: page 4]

NC VIN GND VO UT PG

Инв.№ подл. Подп.и дата Взам.инв.№ Инв.№ дубл.

МИЭМ.467999.001Э3

Изм. | № д ку м | Дата

Comment | Description | Designator | Footprint | LibRef | Quantity
20pF | | C1, C3, C14, C15 | 0603 | Сapacitor | 4
1uF | | C2, C20, C23, C27, C28 | 0603 | Сapacitor | 5
100nF | | C4, C5, C6, C7, C8, C11, C12, C13, C16, C17, C18, C19, C21, C24, C29, C30 | 0603 | Сapacitor | 16
4.3pF | | C9, C10 | 0603 | Сapacitor | 2
10nF | | C22 | 0603 | Сapacitor | 1
10uF | | C25, C26 | TAJB106K025R | PolarizedCapacitor | 2
LD3985M33R | | DA1 | LD3985M33R(SOT-23-5) | LD3985M33R | 1
LD1117S50TR | | DA2 | LD1117S50TR(SOT-223) | LD1117S50TR | 1
LD39050PU33R | | DA3 | LD39050PU33R(DFN6 (3x3mm)) | LD39050PU33R | 1
STM32F030R8T6 | | DD1 | LQFP64-10x10mm | STM32F030R8T6 | 1
STM32F103CBT6 | | DD2 | LQFP48-7x7mm | STM32F103CBT6 | 1
500мА | | FA1 | FCM1608KF-601T05 | Fuse | 1
Oscillator | | G1, G3 | HC49SMD | Oscillator | 2
Oscillator | | G2 | ABS25-32.768KHZ-6-T | Oscillator | 1
0 | | R1, R2, R3, R4, R15, R16, R32 | 0603 | Resistor | 7
4.7kOhm | | R5, R11, R12, R24, R33 | 0603 | Resistor | 5
100Ohm | | R6, R19, R21, R22, R30, R31 | 0603 | Resistor | 6
10kOhm | | R7, R13, R17, R25 | 0603 | Resistor | 4
510Ohm | | R8 | 0603 | Resistor | 1
100kOhm | | R9, R10, R20 | 0603 | Resistor | 3
1.5kOhm | | R14 | 0603 | Resistor | 1
36kOhm | | R18 | 0603 | Resistor | 1
2.7kOhm | | R23 | 0603 | Resistor | 1
22Ohm | | R26, R27, R28, R29 | 0603 | Resistor | 4
1kOhm | | R34 | 0603 | Resistor | 1
Button_4pin | | SA1, SA2 | Button_4pin | Button_4pin | 2
Jumper | | SB1, SB2, SB3, SB4, SB5, SB6, SB7, SB8, SB9, SB10, SB11, SB12 | Jumper | Jumper | 12
led | | V1, V2, V3, V4 | FYLS-0603PGC | led | 4
BAT60JFILM | | VD1, VD2, VD3 | BAT60JFILM | BAT60JFILM | 3
STPS2L30A | | VD4 | STPS2L30A | STPS2L30A | 1
S9013(MMBT9013L/G) | | VT1 | S9013(SOT_23_3) | S9013(MMBT9013L/G) | 1
STS7PF30L | | VT2 | STS7PF30L | STS7PF30L | 1
USB-MINI-B-SMD | | X1 | USB-MINI-B-SMD | USB-MINI-B-SMD | 1
PLS_3 | | X2 | PLS_3 | PLS_3 | 1
PLS_2 | | X3, XP7, XP8, XP9, XP10 | PLS_2 | PLS_2 | 5
PLS_19x2 | | XP1, XP6 | PLS_19x2 | PLS_19x2 | 2
PLS_8 | | XP2, XP5 | PLS_8 | PLS_8 | 2
PLS_6 | | XP3, XP11 | PLS_6 | PLS_6 | 2
PLS_10 | | XP4 | PLS_10 | PLS_10 | 1
PLS_4 | | XP12 | PLS_4 | PLS_4 | 1

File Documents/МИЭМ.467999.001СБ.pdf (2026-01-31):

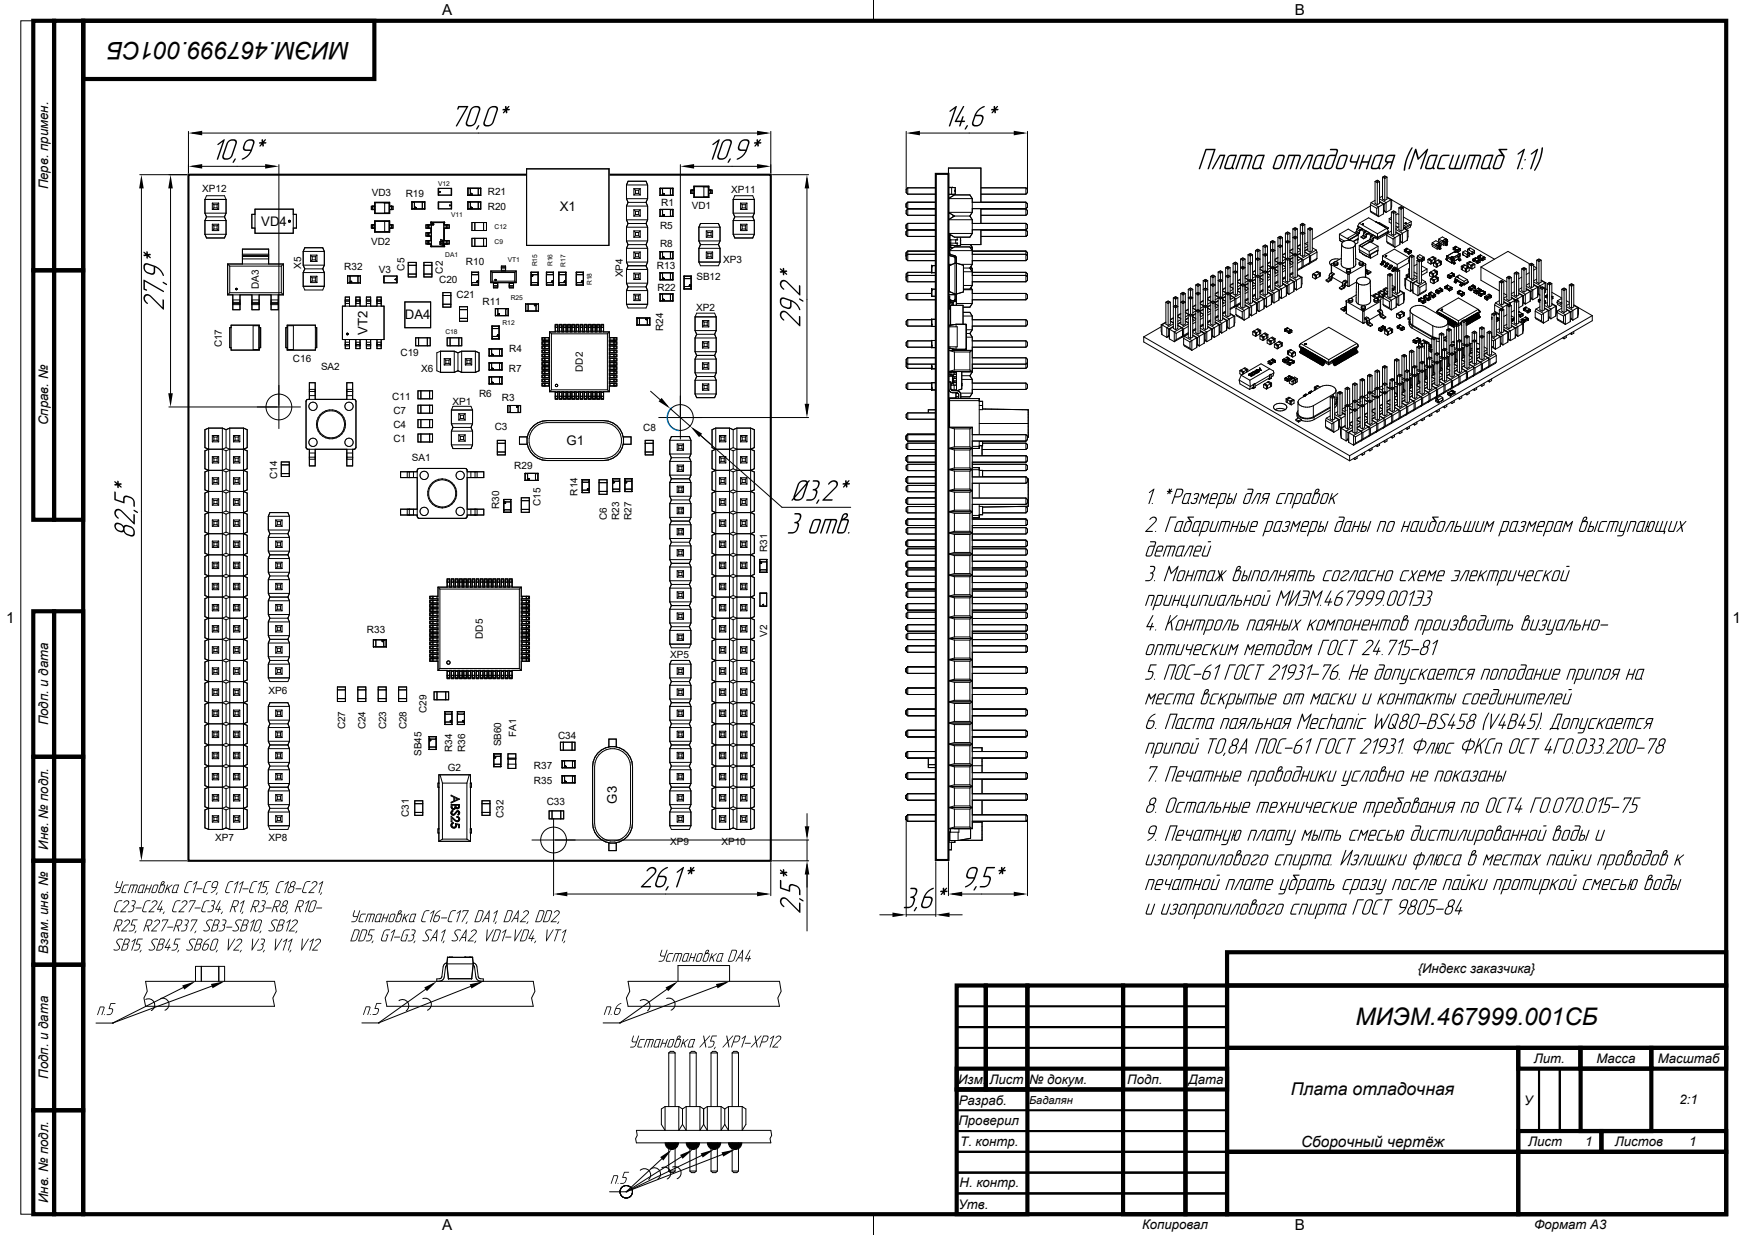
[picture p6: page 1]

Перв. примен. Справ. № Подп. и дата Инв. № подл. Взам. инв. № Подп. и дата Инв. № подл.

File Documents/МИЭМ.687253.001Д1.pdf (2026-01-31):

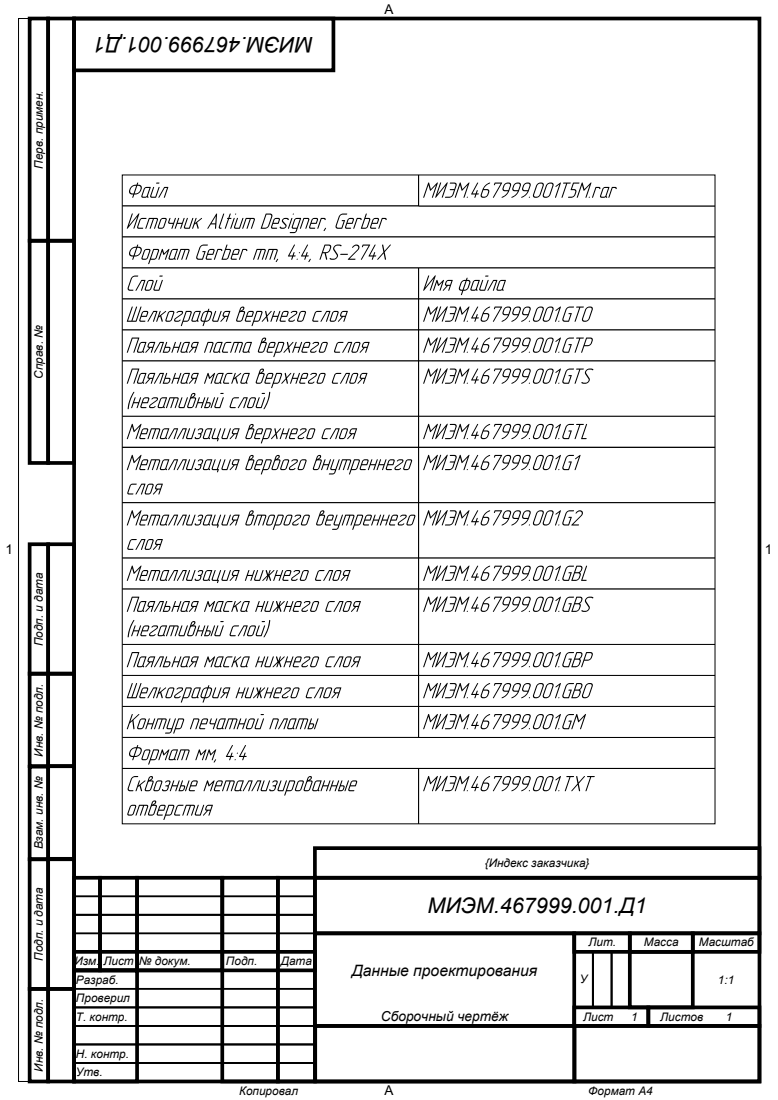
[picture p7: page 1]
Копировал; Формат А4; Сборочный чертёж; {Индекс заказчика}; МИЭМ.467999.001.Д1; Данные проектирования; Лист; Листов; Лит.; Масса; Масштаб; Утв.; Н. контр.; Подп.; Дата

Перв. примен. Справ. № Подп. и дата Инв. № подл. Взам. инв. № Подп. и дата Инв. № подл.

Изм. Лист № докум.
Разраб.
Проверил
Т. контр.

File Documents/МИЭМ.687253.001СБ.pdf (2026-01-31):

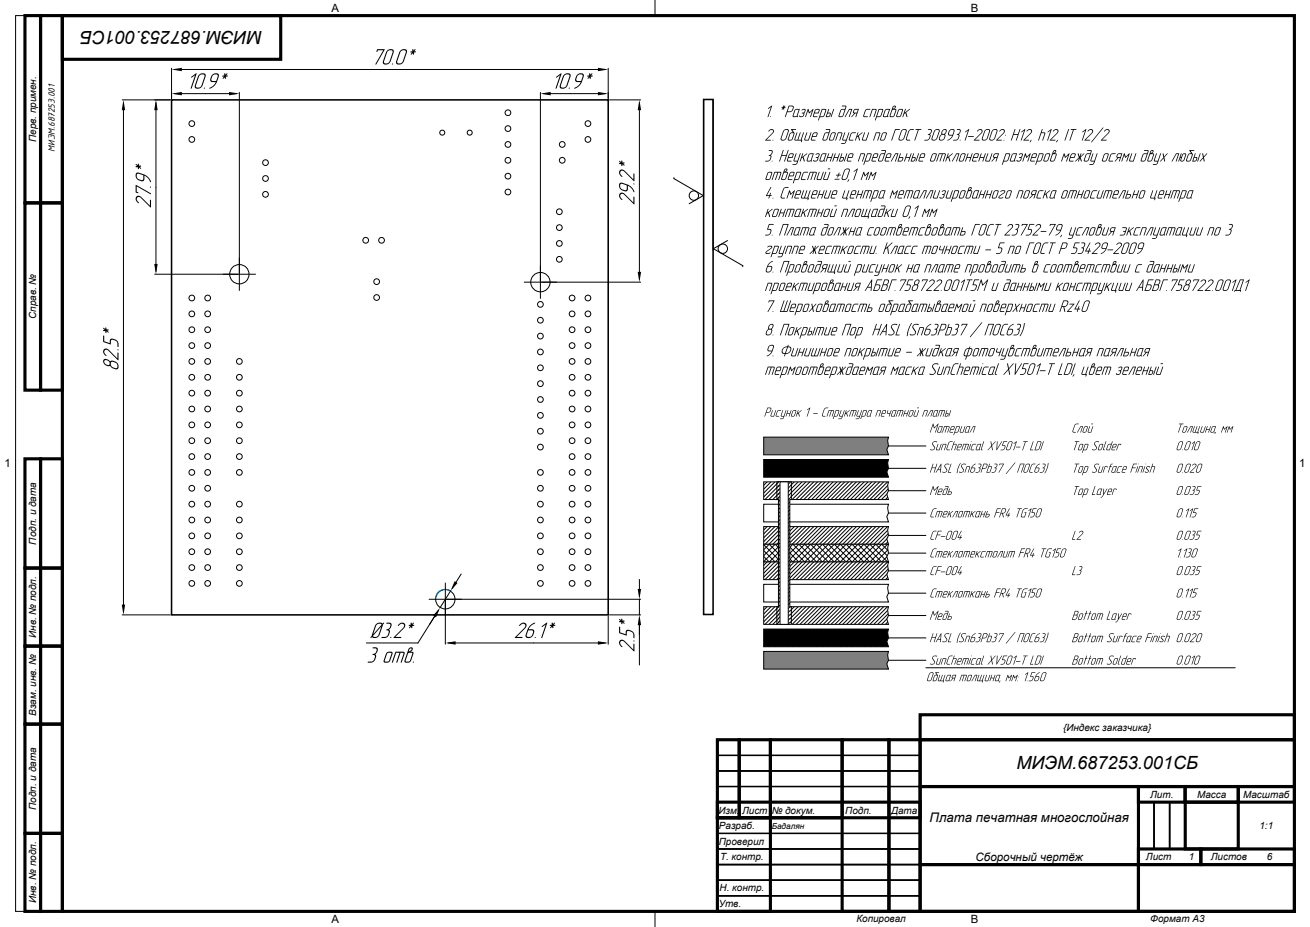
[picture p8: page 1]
Подп.; Дата; Н. контр. Утв.; Лит.; Масса; Масштаб; Лист; Листов; МИЭМ.687253.001СБ; Бадалян; {Индекс заказчика}; Сборочный чертёж; Копировал; Формат А3; МИЭМ.687253.001

Перв. примен. Справ. № Подп. и дата Инв. № подл. Взам. инв. № Подп. и дата Инв. № подл.

Изм. Лист № докум.
Разраб.
Проверил
Т. контр.

Плата печатная многослойная

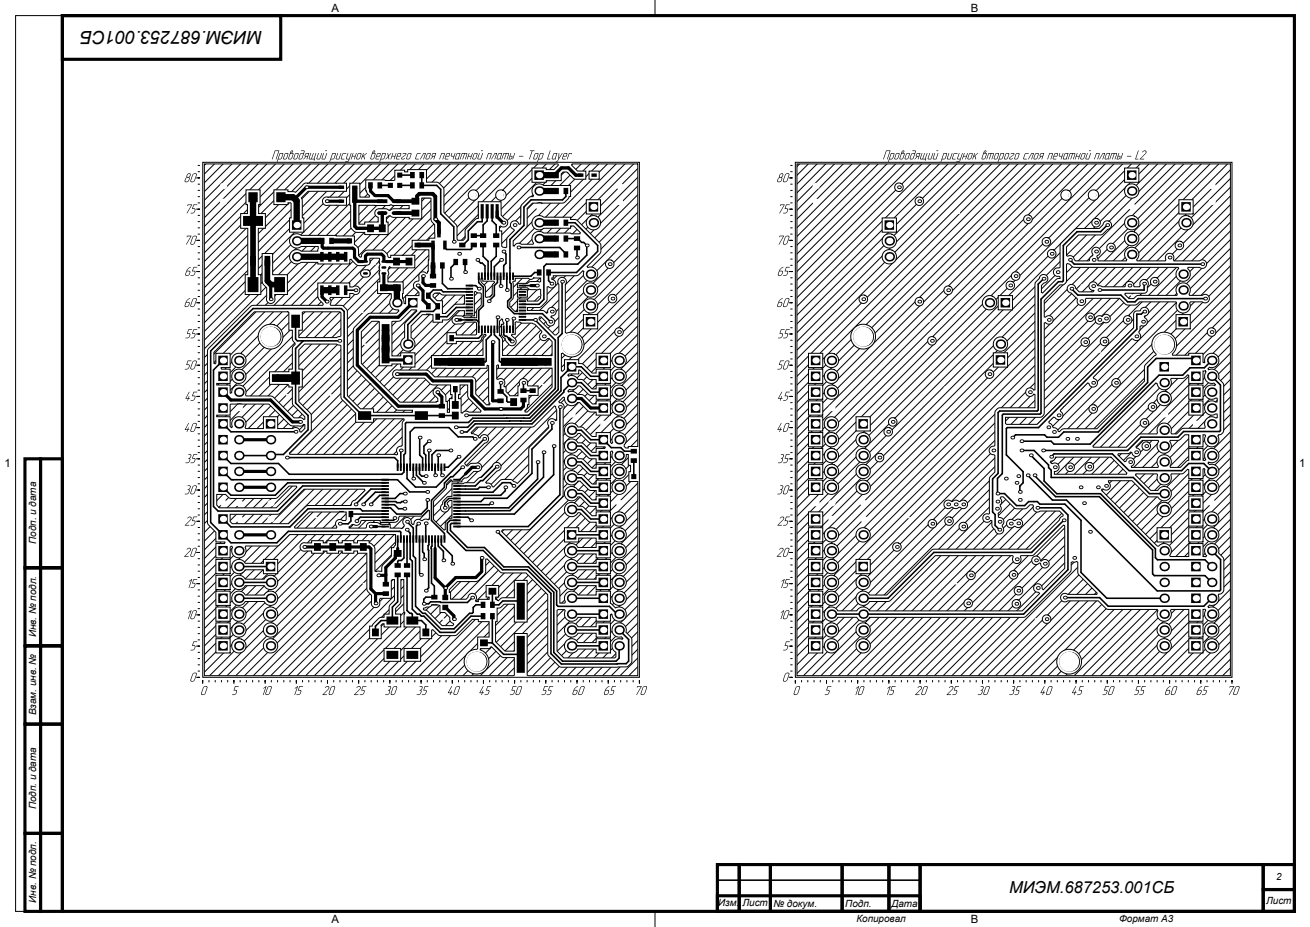
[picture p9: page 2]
МИЭМ.687253.001СБ; Изм. Лист № докум.; Подп.; Дата; Лист

Подп. и дата Инв. № подл. Взам. инв. № Подп. и дата Инв. № подл.

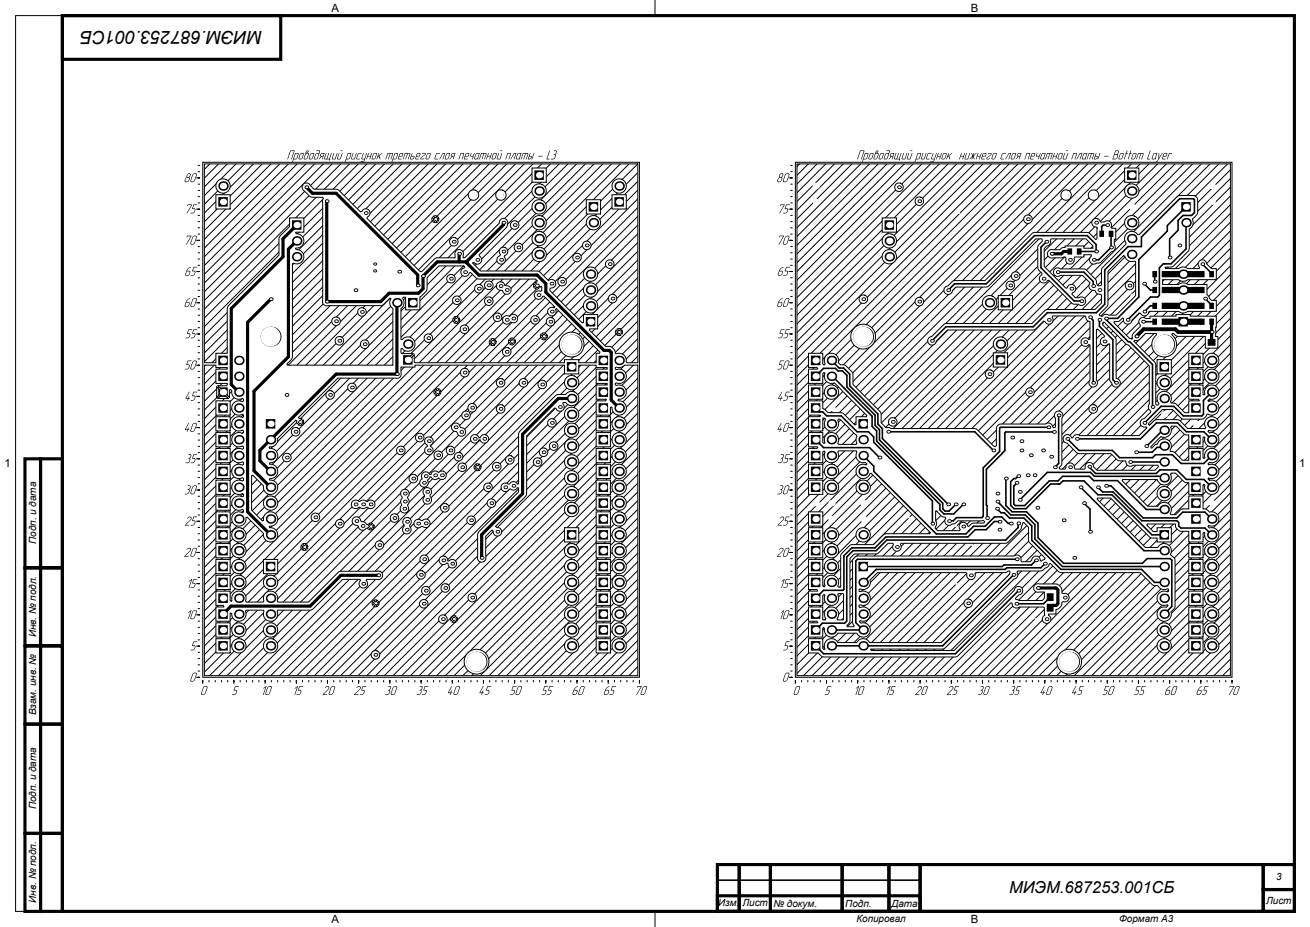
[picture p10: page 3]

Подп. и дата Инв. № подл. Взам. инв. № Подп. и дата Инв. № подл.

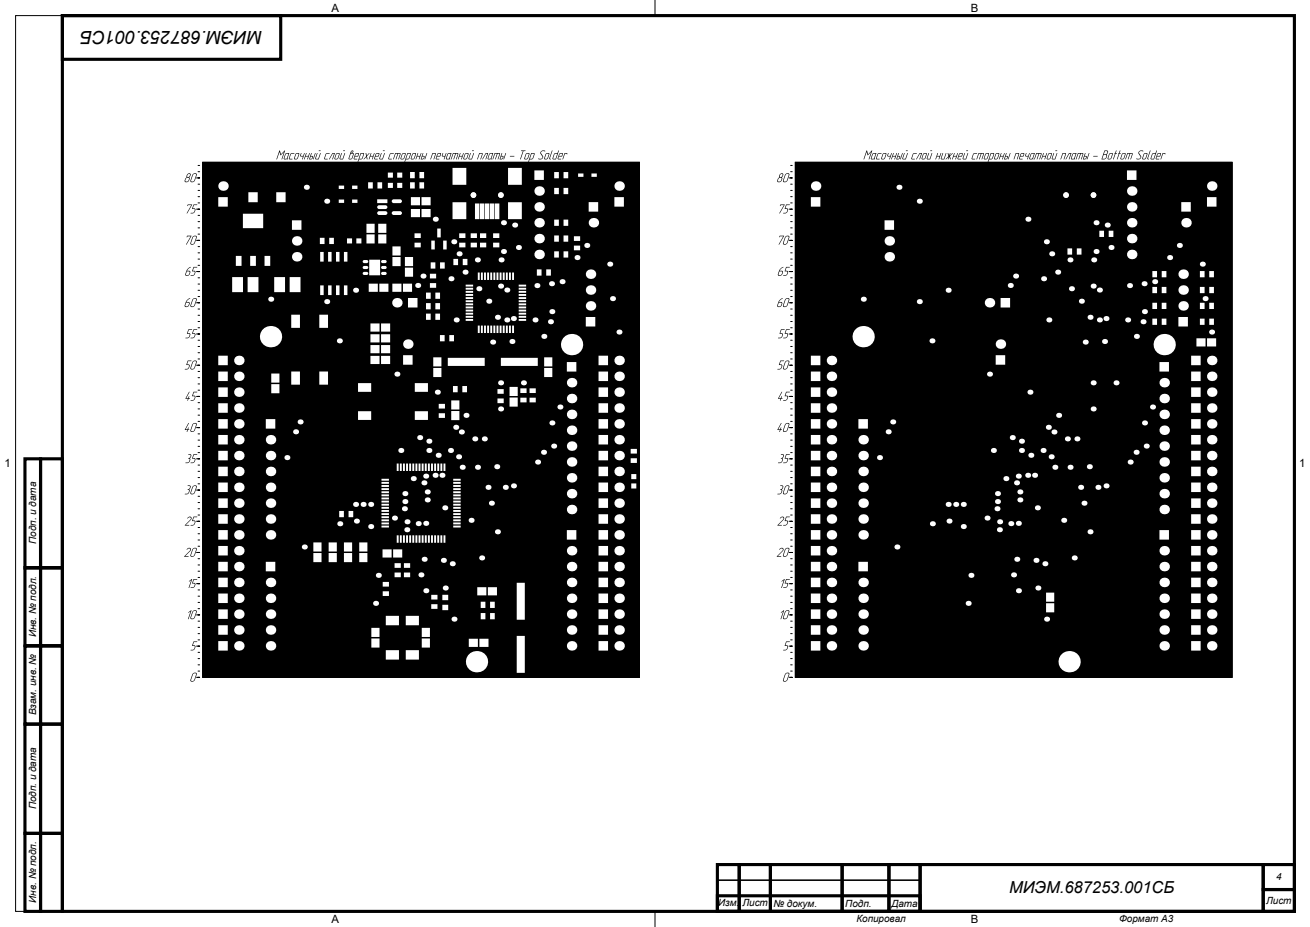
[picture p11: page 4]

Подп. и дата Инв. № подл. Взам. инв. № Подп. и дата Инв. № подл.

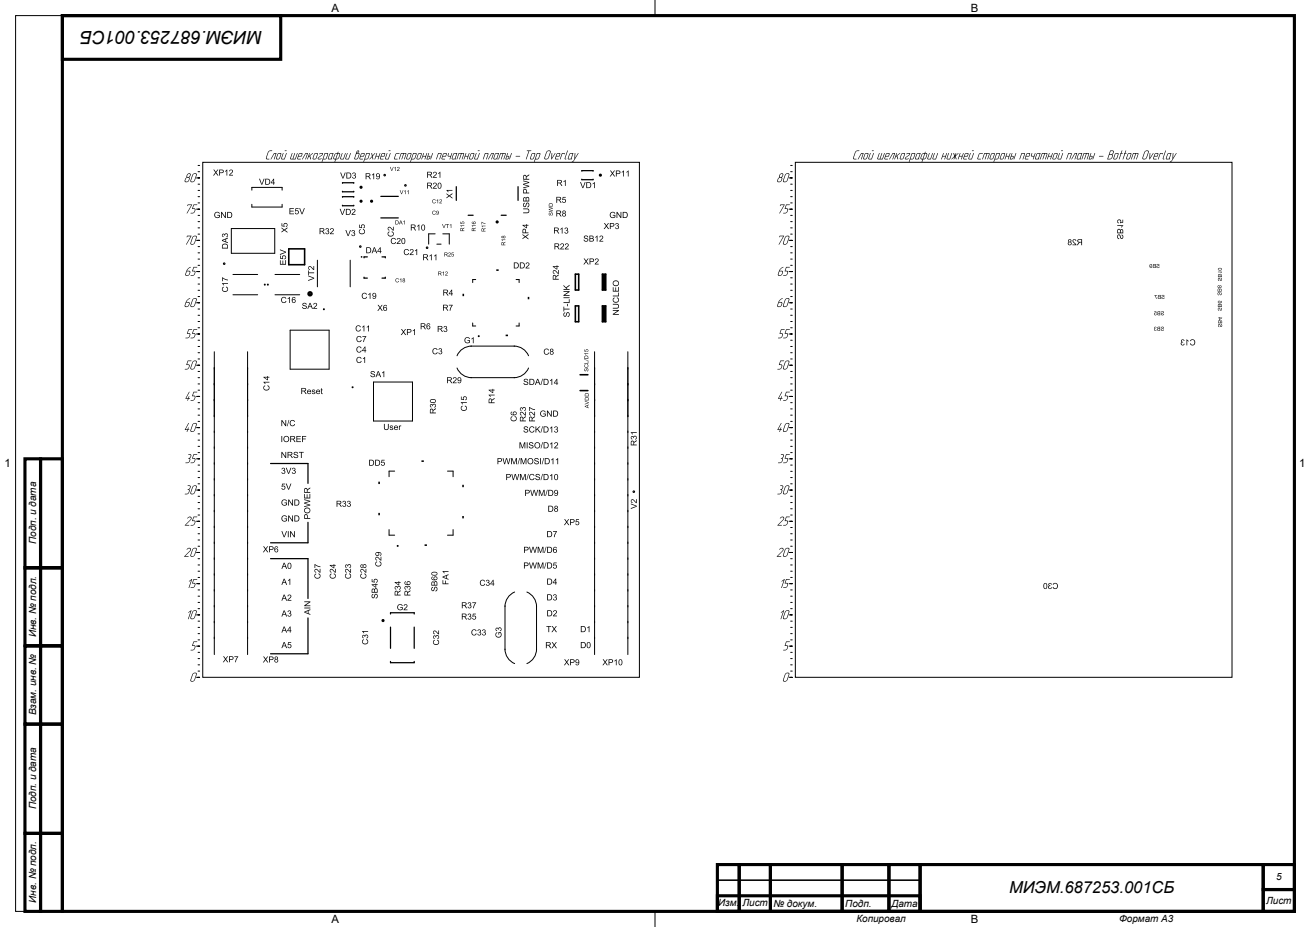
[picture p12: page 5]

Подп. и дата Инв. № подл. Взам. инв. № Подп. и дата Инв. № подл.

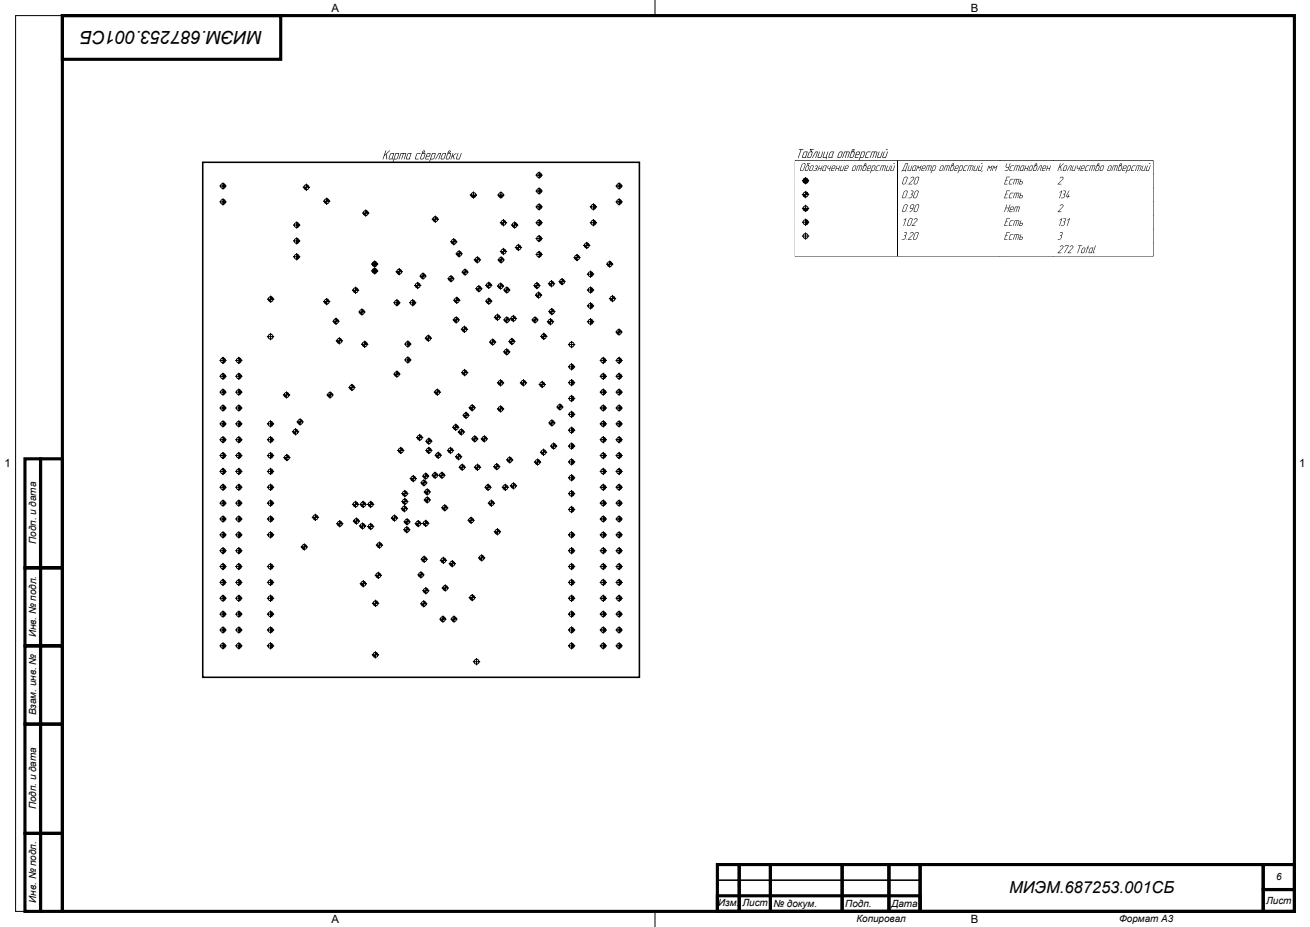
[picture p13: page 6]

Подп. и дата Инв. № подл. Взам. инв. № Подп. и дата Инв. № подл.
